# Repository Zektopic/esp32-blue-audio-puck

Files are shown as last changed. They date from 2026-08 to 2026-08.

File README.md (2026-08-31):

# BlueAudio Puck

**Turn wired headphones wireless.** A pocket-sized Bluetooth audio receiver: it
pairs with a phone or computer as an A2DP sink, decodes the stream on an ESP32,
runs it through a parametric equaliser, and pushes PCM out over I²S to an
external DAC and headphone amplifier feeding a 3.5 mm jack.






> [!IMPORTANT]
> **Original ESP32 only.** A2DP rides on Bluetooth Classic (BR/EDR), which
> Espressif removed from the ESP32-S3 and ESP32-C3. Those parts are BLE-only and
> cannot run this firmware — and they cannot fall back to LE Audio either, since
> that needs BLE 5.2 isochronous channels and they are 5.0.

---

## What it does

| | |
| --- | --- |
| **A2DP sink** | Pairs as a headphone. SBC decode, 16/32/44.1/48 kHz, mono or stereo. |
| **I²S output** | 16-bit PCM to an external DAC. APLL-clocked for accurate 44.1 kHz. |
| **AVRCP, both roles** | Phone's volume slider works; track metadata comes back; buttons drive transport. |
| **Parametric EQ** | Five biquad bands per channel, sample-rate aware, ~16% of one core when fully active. |
| **OLED status screen** | 128x64 SSD1306 over I2C: signal, track, artist, transport, volume, battery. |
| **Battery gauge** | ADC on a divider, Li-po curve, low and critical warnings. |
| **Physical UI** | One multi-function button, optional volume keys, optional PWM status LED. |
| **Power policy** | Capped TX power, 80–160 MHz frequency scaling, deep sleep on idle. |
| **Bounded pairing** | Discoverable only when you ask for it, not permanently. |

## Signal chain

```mermaid
flowchart LR
    SRC["Phone / PC<br/><i>A2DP source</i>"]
    subgraph PUCK["BlueAudio Puck"]
        direction LR
        BT["ESP32<br/>Bluedroid A2DP sink<br/>SBC decode"]
        DSP["Ring buffer<br/>+ EQ + volume"]
        DAC["PCM5102A<br/>I²S DAC"]
        AMP["Headphone amp"]
        OLED["SSD1306 OLED<br/><i>I²C</i>"]
        BATT["Li-po + divider<br/><i>ADC</i>"]
    end
    JACK["3.5 mm<br/>headphones"]

    SRC -- "Bluetooth Classic" --> BT
    BT -- "PCM frames" --> DSP
    DSP -- "I²S" --> DAC
    DAC -- "line level" --> AMP
    AMP --> JACK
    BT -. "track, volume" .-> OLED
    BATT -. "percent" .-> OLED
```

## Firmware architecture

The single rule everything else follows: **Bluedroid callbacks only enqueue.**
Anything slow in stack context stalls the radio and comes out as dropouts.

```mermaid
flowchart TD
    subgraph BTCTX["Bluetooth stack context — never blocks"]
        A2DP["A2DP data callback"]
        EVT["GAP / A2DP / AVRCP<br/>event callbacks"]
    end
    subgraph APPCTX["Application task — core 0"]
        WORK["work dispatcher<br/><i>bt_core</i>"]
    end
    subgraph AUDCTX["Audio writer task — core 1"]
        RB[("ring buffer<br/>32 kB")]
        EQ["biquad cascade<br/><i>audio_dsp</i>"]
        VOL["volume gain"]
        I2S["i2s_channel_write"]
    end

    A2DP -- "non-blocking send" --> RB
    EVT -- "dispatch" --> WORK
    WORK -- "start / stop / format" --> RB
    RB --> EQ --> VOL --> I2S

    classDef ctx fill:none,stroke-dasharray:4 3
    class BTCTX,APPCTX,AUDCTX ctx
```

Every cost — the blocking I²S write, the EQ, the gain — lives on the writer
task, pinned to the core the radio is not using.

### Components

| Component | Responsibility |
| --- | --- |
| [`bt_core`](components/bt_core/) | Stack bring-up, work queue between Bluedroid and the app task, bond management |
| [`audio_sink`](components/audio_sink/) | I²S channel, ring buffer, writer task, volume gain |
| [`audio_dsp`](components/audio_dsp/) | Parametric biquad equaliser and its benchmark |
| [`puck_avrcp`](components/puck_avrcp/) | AVRCP controller and target: volume, metadata, transport keys |
| [`puck_ui`](components/puck_ui/) | Button gestures and PWM status LED |
| [`puck_display`](components/puck_display/) | SSD1306 panel driver, framebuffer, screens |
| [`puck_battery`](components/puck_battery/) | ADC sensing and the Li-po discharge curve |
| [`puck_power`](components/puck_power/) | TX power, frequency scaling, idle deep sleep |

These are written from scratch against the IDF v5.5 API rather than reusing the
ESP-IDF example's shared components, which are pulled in by `${IDF_PATH}` path
and would make the repository unbuildable anywhere else. See
[docs/design-notes.md](docs/design-notes.md) for what that surfaced.

## Hardware

The pin map follows the layout that lets a PCM5102A board sit **directly under**
an ESP32 devkit on short solder bridges, rather than the pins that happen to be
convenient on a breadboard.

| ESP32 | Signal | Goes to |
| --- | --- | --- |
| GPIO 4 | I²S BCK | PCM5102A `BCK` |
| GPIO 15 | I²S LRCK | PCM5102A `LRCK` |
| GPIO 2 | I²S DATA | PCM5102A `DIN` |
| GPIO 21 | I²C SDA | SSD1306 `SDA` |
| GPIO 22 | I²C SCL | SSD1306 `SCL` |
| GPIO 32 | BT1 | to GND — next track / volume up |
| GPIO 33 | BT2 | to GND — play/pause / pairing (RTC pin, wakes from deep sleep) |
| GPIO 27 | BT3 | to GND — previous track / volume down |
| GPIO 35 | Battery sense | divider midpoint (optional, unfitted by default) |
| 3V3, GND | Power | both boards |

> [!NOTE]
> **No MCLK/SCK wire to the DAC.** Solder the `SCK` bridge on the front of the
> PCM5102A instead and it derives its own clock from BCK. Leave the ESP32 pin
> beneath it unconnected — a strip of tape stops it shorting to anything.

> [!IMPORTANT]
> **GPIO 2 is the devkit's on-board LED pin and a strapping pin.** It now
> carries I²S data, so the on-board LED flickers with audio — harmless, and the
> reason `PUCK_LED_GPIO` defaults to *not fitted*. It also means the board may
> refuse to enter download mode if the DAC holds that line high during reset;
> holding **BOOT** while flashing works around it.

PCM5102A jumpers — these cause most "no sound" reports:

| Pin | Set to | Why |
| --- | --- | --- |
| SCK bridge | **soldered** | Runs the internal PLL, so no MCLK wire is needed |
| XSMT | 3V3 | Release soft-mute. Low means muted. |
| FMT | GND | I²S (Philips) frame format, which is the firmware default |
| FLT | GND | Normal latency filter |
| DEMP | GND | De-emphasis off |

**Battery sensing** is optional and off by default. To fit it, run a divider
from the cell to GPIO 35 — two 100 kΩ resistors give 2:1, fits the ADC range
with a full 4.2 V cell, and draws about 21 µA — then set
`PUCK_BATTERY_ADC_GPIO=35` and the ratio to match your resistors.

Full parts discussion, power budget and the roadmap to a custom board:
[docs/hardware.md](docs/hardware.md).

## Building

Requires **ESP-IDF v5.5.4**.

```powershell
& 'C:\Espressif\tools\Microsoft.v5.5.4.PowerShell_profile.ps1'
idf.py set-target esp32
idf.py build
idf.py -p COM10 flash monitor
```

`sdkconfig` is generated and gitignored; `sdkconfig.defaults` is the source of
truth. Project settings live under **BlueAudio Puck** in `idf.py menuconfig`.

Expected first output:

```
I (593) puck: BlueAudio Puck booting (IDF v5.5.4)
I (603) audio_sink: ready: bck=4 ws=15 dout=2, 32 kB buffer, prefetch 25%
I (603) audio_dsp: 5-band equaliser ready at 44100 Hz (off, 0 active)
I (613) ssd1306: 128x64 panel at 0x3c on SDA=21 SCL=22
I (1313) bt_core: controller up, address ...
I (1373) puck: no bonded sources; discoverable as "BlueAudio Puck"
```

> [!TIP]
> If flashing fails with `Wrong boot mode detected (0x13)`, hold the **BOOT**
> button as the flash starts. Some devkits — and any board where GPIO 2 is
> loaded by the DAC — will not auto-reset into download mode.

## Using it

| Button | Tap | Hold |
| --- | --- | --- |
| **BT1** | Next track | Volume up — repeats while held |
| **BT2** | Play / pause | Pairing window (1.5 s) · forget all bonds (5 s) |
| **BT3** | Previous track | Volume down — repeats while held |

One action per press, no multi-tap timing to get right. Holding a volume button
sweeps rather than nudging once, at roughly four seconds end to end.

### The screen

| Screen | When |
| --- | --- |
| Splash | While the stack comes up |
| `PAIRING` | Discoverable, waiting for a source |
| `IDLE` | Connectable, nothing connected |
| Now playing | Signal, track and artist, transport state, volume bar, battery |

The top-left **signal meter** shows link quality while a source is connected.
It is hidden when nothing is connected, because bars against no link would be
meaningless. Note what Bluetooth Classic actually reports — see below.

The track title scrolls when it is too long, pausing at each end — continuous
sliding is much harder to read. Volume changes raise a brief toast over the
bottom of the screen. Battery shows as a percentage and an icon, or `USB` when
no sense divider is fitted.

> [!NOTE]
> **The signal meter will usually read full, and that is correct.** Bluetooth
> Classic does not report absolute signal strength. It reports a delta from the
> *Golden Receive Power Range* — the window the controller works to keep the
> link inside — so **zero means healthy**, not "no signal". The value only goes
> negative once the link is genuinely struggling. Read the bars as *fine /
> getting worse / about to drop out*, not as dBm.

At start-up the panel runs a **self test** — solid fill, checkerboard, then a
border — before any text is drawn. None of it uses the font, which is the
point: it separates a bus or panel fault from a text-rendering fault.

### The optional LED

| LED | Meaning |
| --- | --- |
| Fast blink | Discoverable, waiting for a source |
| Slow breathe | Connected, not streaming |
| Steady dim | Audio playing |
| Triple flash | Something failed to start |

Unfitted by default, because GPIO 2 now carries I²S data and the screen shows
the same states in words.

Volume normally comes from the phone over AVRCP absolute volume. Dedicated
volume buttons are optional and unfitted by default.

## Configuration

All under `idf.py menuconfig` → **BlueAudio Puck**. Every GPIO accepts `-1` for
"not fitted".

| Option | Default | Notes |
| --- | --- | --- |
| `PUCK_BT_DEVICE_NAME` | `BlueAudio Puck` | Shown in the pairing list |
| `PUCK_I2S_BCK/LRCK/DOUT_GPIO` | 4 / 15 / 2 | Direct-solder layout |
| `PUCK_I2C_SDA/SCL_GPIO` | 21 / 22 | `-1` disables the display |
| `PUCK_DISPLAY_I2C_ADDRESS` | 0x3C | Some modules strap to 0x3D |
| `PUCK_DISPLAY_CONTRAST` | 127 | |
| `PUCK_DISPLAY_SELF_TEST` | on | ~1.4 s of boot time |
| `PUCK_RSSI_POLL_SECONDS` | 3 | How often the signal meter updates |
| `PUCK_BATTERY_ADC_GPIO` | 35 | ADC1 pins only (32–39); `-1` if no divider |
| `PUCK_BATTERY_DIVIDER_RATIO_X100` | 200 | 2:1; must match your resistors |
| `PUCK_BT1/BT2/BT3_GPIO` | 32 / 33 / 27 | Active low, internal pull-up |
| `PUCK_VOLUME_STEP` | 6 | Per repeat, of 127 |
| `PUCK_LED_GPIO` | -1 | GPIO 2 is now I²S data |
| `PUCK_I2S_SLOT_FORMAT` | Philips | Must match the DAC's `FMT` pin |
| `PUCK_I2S_USE_APLL` | on | Accurate 44.1 kHz, slightly more current |
| `PUCK_AUDIO_RINGBUF_KB` | 32 | Larger rides out radio retries, costs RAM and latency |
| `PUCK_AUDIO_PREFETCH_PERCENT` | 25 | ≈46 ms cushion; also what an underrun costs to rebuild |
| `PUCK_AUDIO_WRITER_CORE` | 1 | Keep off core 0, which runs the radio |
| `PUCK_EQ_BANDS` | 5 | A ceiling, not a fixed price — flat bands cost nothing |
| `PUCK_EQ_ENABLED_AT_BOOT` | off | Starts transparent |
| `PUCK_EQ_BENCHMARK_AT_BOOT` | off | Times the cascade; see below |
| `PUCK_PAIRING_WINDOW_SECONDS` | 120 | How long a long press stays discoverable |
| `PUCK_BT_TX_POWER_LEVEL` | 7 (+9 dBm) | Ceiling; lower it for runtime |
| `PUCK_BT_TX_POWER_MIN_LEVEL` | 4 (0 dBm) | Floor power control may drop to |
| `PUCK_CPU_MAX/MIN_FREQ_MHZ` | 160 / 80 | Dynamic frequency scaling |
| `PUCK_IDLE_SLEEP_MINUTES` | 15 | Counts only while disconnected; 0 disables |

## Measured

| What | Result |
| --- | --- |
| EQ cost, 5 stereo biquad sections | 1337 µs per 360-frame block = **16% of one core** at 160 MHz |
| EQ cost per band | ~3.2% of a core, so roughly 30 sections before saturating one |
| OLED bus scan | One device ACKs at **0x3C** on SDA 21 / SCL 22 |
| Full-frame OLED refresh | 1025 bytes at 400 kHz ≈ 21 ms, hence a few Hz refresh |
| Firmware image | ~1.04 MB (needs the large single-app partition; the 1 MB default does not fit) |
| Free heap after boot | ~210 kB |
| Pairing window | Closes at 120.0 s, verified on hardware |

Power draw has **not** been measured. The estimates in
[docs/hardware.md](docs/hardware.md) are datasheet-derived, and devkit
measurements would be meaningless anyway — the USB-UART bridge and the AMS1117
regulator dominate a devkit's draw whatever the firmware does.

## Documentation

- [hardware/](hardware/) — KiCad schematic and PCB for a single-board version (unrouted, unfabricated)
- [docs/hardware.md](docs/hardware.md) — parts, wiring, power budget, board roadmap
- [docs/design-notes.md](docs/design-notes.md) — why the firmware is shaped this way, and the IDF bugs it avoids
- [docs/troubleshooting.md](docs/troubleshooting.md) — no sound, no pairing, dropouts, build failures
- [SECURITY.md](SECURITY.md) — threat model, pairing decisions, accepted risks

## Status

Working: builds, boots, pairs, advertises correctly, AVRCP negotiates, power and
UI subsystems initialise. Verified on an ESP32-WROOM devkit.

**Not yet verified:** audio actually coming out, and what the OLED renders. The
I²C bus and the panel address are confirmed by a scan on real hardware, but the
glyphs and layout have not been seen. The I²S configuration, the EQ response and
the end-to-end audio path are reasoned against the ESP-IDF v5.5.4 driver
sources, not heard. Battery sensing has no cell fitted, so only its
"not fitted" path runs.

## Prior art

Written from scratch, but these informed the design and are worth reading:

- [WillyBilly06/ESP32-A2DP-SINK-WITH-CODECS-UPDATED](https://github.com/WillyBilly06/ESP32-A2DP-SINK-WITH-CODECS-UPDATED) — LDAC/aptX/AAC patched into the IDF stack, which proves the SBC ceiling is firmware and not silicon
- [YetAnotherElectronicsChannel/ESP32_4CH_DSP_BT_AMPLIFIER](https://github.com/YetAnotherElectronicsChannel/ESP32_4CH_DSP_BT_AMPLIFIER) — parametric EQ with a Wi-Fi config UI, full schematics and gerbers
- [ESP32 as BT receiver with DSP capabilities](https://hackaday.io/project/166122-esp32-as-bt-receiver-with-dsp-capabilities) — biquads in the a2dp_sink render path; left the biquad budget as an open question, which [docs/design-notes.md](docs/design-notes.md) answers
- [gangg111/ESP32-Bluetooth-Audio-Receiver](https://github.com/gangg111/ESP32-Bluetooth-Audio-Receiver) — PCM5102A plus an OLED showing track metadata
- [pschatzmann/ESP32-A2DP](https://github.com/pschatzmann/ESP32-A2DP) — the reference Arduino-side A2DP library

## Licence

MIT — see [LICENSE](LICENSE).

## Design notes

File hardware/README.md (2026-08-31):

# BlueAudio Puck carrier board, rev A

KiCad 10 schematic and PCB for a single-board version of the puck: ESP32-WROOM-32U,
PCM5102A DAC, Li-po charging, two separate 3V3 rails, OLED header, three user
buttons and a 3.5 mm output — 60 × 64 mm, drawn to JLCPCB's two-layer rules.

| File | What it is |
| --- | --- |
| [`blueaudio-puck.kicad_pro`](blueaudio-puck.kicad_pro) | Project — open this |
| [`blueaudio-puck.kicad_sch`](blueaudio-puck.kicad_sch) | Schematic |
| [`blueaudio-puck.kicad_pcb`](blueaudio-puck.kicad_pcb) | Board |
| [`bom.csv`](bom.csv) | Bill of materials |
| [`preview/`](preview/) | SVG renders of both |
| [`scripts/`](scripts/) | The generator — see below |

## Read this before you order anything

> [!CAUTION]
> **Not finished: eight nets still need routing by hand.**
>
> Everything the generator lays is DRC-clean — **zero clearance violations,
> zero shorts, zero hole-clearance errors** under JLCPCB's rules. But 25 of 33
> nets are routed, not 33, and the remaining eight are unconnected copper:
>
> `+3V3A` · `AUDIO_L` · `CC1` · `CC2` · `DAC_LDOO` · `DAC_VNEG` · `I2S_BCK` · `I2S_LRCK`
>
> All eight are around the two fine-pitch parts — the TSSOP-20 DAC and the
> USB-C receptacle. Open the board in Pcbnew and its interactive router will
> finish them far faster and better than the one in `scripts/`. Do not order
> anything until DRC reports zero unconnected items.

> [!WARNING]
> **Nothing here has been fabricated or tested.** It passes ERC and the DRC
> checks that apply to an unrouted board. It has never been a physical object.
> Review the schematic against the datasheets before you spend money.

## Verification

Actually run, with the output quoted rather than summarised:

```
$ kicad-cli sch erc --severity-error --severity-warning
Found 4 violations                    # all lib_symbol_mismatch, see below

$ kicad-cli pcb drc --severity-error --severity-warning
Found 25 violations
Found 22 unconnected items
```

The schematic is clean: **zero electrical errors**, no unconnected pins, no
dangling labels, no malformed outline. All four ERC warnings are
`lib_symbol_mismatch` on KiCad's *derived* symbols — the two regulators and the
two transistors. Cosmetic; see below.

The board has **no electrical errors either**. Breaking the 25 down:

| Count | Kind | Status |
| --- | --- | --- |
| 22 | `unconnected_items` | **Must fix** — the eight unrouted nets |
| 15 | `silk_over_copper` | Cosmetic; every fab ignores it |
| 10 | `silk_overlap` | Cosmetic |

No `clearance`, no `shorting_items`, no `hole_clearance`. That took three fixes
to the router's geometry, each of which had produced copper that looked right
and was not — they are written up in the file that makes them:

- **A track is not a point.** A 0.4 mm power track centred on a 0.25 mm grid
  cell spills into its neighbours; checking only the cell it steps through let
  it sit 0.15 mm from a pad. Same for vias, which are 0.6 mm across — one
  landed on top of another net's track.
- **Clearance belongs in the check, not the map.** Growing a clearance halo
  around every pad *and* checking a track's own clearance against it demanded
  the gap twice, which makes escaping a 0.65 mm pitch TSSOP impossible.
- **Holes are stricter than copper.** Copper-to-hole is 0.25 mm where
  copper-to-copper is 0.15 mm, so drilled pads are claimed slightly larger than
  their copper.

The router still gets 25 of 33 nets rather than all of them. It routes in order
and never rips up an earlier net to make room, which is the difference between
it and a real autorouter.

The two ERC warnings are `lib_symbol_mismatch` on `AP2112K-3.3` and
`LP2985-3.3`. Both are KiCad *derived* symbols (`extends`), and the generator
flattens them to embed them; the flattened copy differs cosmetically from the
library's. Connectivity and pin numbering are unaffected. Eeschema's
*Update Symbols from Library* clears it.

The silkscreen warnings are reference designators sitting over pads. Normal for
auto-placed boards, ignored by every fab, and worth tidying only once placement
is final.

## How it is generated

Both files come from **one** netlist, in [`scripts/design.py`](scripts/design.py).

That matters more than it sounds. A schematic and a PCB authored separately
disagree about connectivity, and KiCad does not tell you until someone runs ERC
and gets a wall of errors. One source, two emitters, no drift.

```
scripts/design.py         parts, nets, no-connects, board size  <- edit this
scripts/kisym.py          pulls symbols out of the KiCad libraries
scripts/check_sheet.py    catches stubs from different nets touching
scripts/gen_schematic.py  emits the .kicad_sch
scripts/gen_pcb.py        emits the .kicad_pcb (needs KiCad's python)
```

To regenerate:

```bash
cd hardware/scripts
python design.py          # netlist self-check
python check_sheet.py     # no two nets touching
python gen_schematic.py
"C:/Users/manup/AppData/Local/Programs/KiCad/10.0/bin/python.exe" gen_pcb.py
```

`gen_pcb.py` needs KiCad's bundled interpreter — `pcbnew` lives only there.

Symbols and footprints are copied from the installed libraries rather than
transcribed, so the output files are self-contained and open on a machine with
no libraries configured. A hand-typed pin table is exactly the kind of error
nothing but a human eye can catch.

### Once you edit it by hand

The generators overwrite their outputs. Move the files out of `hardware/`, or
stop regenerating, once you start editing in KiCad — which you will, because
routing is the next step.

## The design

```
USB-C ──> MCP73831 ──> Li-po ──┬──> AP2112K ──> +3V3  ──> ESP32, OLED, DAC digital
                               └──> LP2985  ──> +3V3A ──> DAC analogue
```

**Two regulators from the cell, not one.** The DAC's analogue rail gets its own
low-noise LP2985 with a bypass capacitor. Sharing a rail with a Bluetooth radio
is what makes a DAC hiss, and `docs/hardware.md` said so before this board
existed.

**No MCLK.** The PCM5102A has `SCK` grounded and runs from its internal PLL,
matching the hand-built prototype and what the firmware expects.

**JP1 sits in series with I²S data on GPIO 2.** That pin is a boot strapping
pin, and a DAC loading it is why the prototype needs BOOT held to flash. Lift
the jumper and the board flashes normally.

**Battery sense** is R7/R8, a 2:1 divider into GPIO 35, matching
`PUCK_BATTERY_DIVIDER_RATIO_X100=200`.

**Three user buttons** on GPIO 32/33/27, matching the firmware — SW1 is BT1
(next / volume up), SW2 is BT2 (play-pause / pairing), SW3 is BT3 (previous /
volume down). All active low straight to ground; the ESP32's internal pull-ups
mean no external resistors. SW4 and SW5 are RESET and BOOT.

Note there is **no LED on GPIO 27** on this board. The Kconfig help for
`PUCK_LED_GPIO` suggests 27 for an external status LED, which would collide
with BT3 on a breadboard. Here the only LED is D1, the charge indicator on
`CHG_STAT`, so GPIO 27 is unambiguously BT3.

### Where it departs from `docs/hardware.md`

Both departures are deliberate and both are rev B work:

**No buck-boost.** `docs/hardware.md` specifies a TPS63020 for efficiency —
roughly 20–25% more runtime than an LDO. KiCad's standard library has no symbol
for it, and inventing one is precisely the silent error this generator exists to
avoid. Rev A uses LDOs and pays the efficiency.

**No headphone amplifier.** The PCM5102A is line level: audible on 32 Ω
headphones but quiet, exactly as the docs warn. A TPA6132A2 is the rev B
addition, and it is QFN-16 — it would make this board far harder to hand-build.

## Manufacturing rules

Written into the project file, so DRC enforces them rather than leaving them as
folklore. JLCPCB's standard two-layer process, with margin:

| | JLC minimum | Used here |
| --- | --- | --- |
| Track width | 0.127 mm | 0.20 mm |
| Clearance | 0.127 mm | 0.15 mm |
| Via drill | 0.20 mm | 0.30 mm |
| Via diameter | drill + 0.26 | 0.60 mm |
| Annular ring | 0.13 mm | 0.15 mm |
| Hole to hole | 0.50 mm | 0.50 mm |
| Track to outline | 0.20 mm | 0.50 mm |

Only clearance sits near a limit, and it is still 18% above JLC's floor. The
0.05 mm it frees up per side compared with KiCad's 0.2 mm default is most of
what lets the congested area route at all.

**Teardrops are configured but not generated.** The parameters are in the
project file; KiCad adds the actual teardrops on demand. Run *Edit → Teardrops
→ Add Teardrops* in Pcbnew once routing is finished — doing it before then
would only have to be redone.

## What is left to do

1. **Route the last eight nets** in Pcbnew: `+3V3A`, `AUDIO_L`, `CC1`, `CC2`,
   `DAC_LDOO`, `DAC_VNEG`, `I2S_BCK`, `I2S_LRCK`. All are around the TSSOP-20
   DAC and the USB-C part. The interactive router will do this in minutes.
2. **Add teardrops** once routing is done.
3. **Check the antenna keep-out.** The WROOM-32U has an external connector so
   there is no PCB antenna to clear, but leave the module's edge unpoured.
4. **Re-run DRC** and get it to zero before ordering anything.
5. **Review against datasheets.** Especially the MCP73831 programming resistor
   (R5 = 2 kΩ, about 500 mA) against your cell's charge rate.
6. **Rounded corners** were dropped — arcs whose endpoints did not meet left the
   outline open, and KiCad will not guess. Add them in Pcbnew, where the editor
   keeps the ends joined.

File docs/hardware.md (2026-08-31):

# Hardware

Parts, wiring, power budget and the route from a breadboard to a puck.

> [!NOTE]
> The pin map below is **as wired**. The I²C bus and OLED address are confirmed
> by a scan on the real board. Everything about audio and power is still
> unverified: no DAC has produced sound yet, no cell is fitted, and the power
> figures are datasheet-derived estimates rather than measurements.

## Why the original ESP32

A2DP rides on Bluetooth Classic (BR/EDR). Espressif removed Classic from every
chip after the original ESP32, so:

| Part | Bluetooth | A2DP sink? |
| --- | --- | --- |
| ESP32 (Xtensa) | Classic BR/EDR + BLE | **Yes** |
| ESP32-S3 | BLE 5.0 only | No |
| ESP32-C3 | BLE 5.0 only | No |

The S3 and C3 cannot fall back to LE Audio either — that needs BLE 5.2
isochronous channels and they are 5.0. This is silicon, not firmware.

Use a **WROOM-32U with an external antenna** if you can. A puck lives in a
pocket or bag with a body between it and the phone, and builders consistently
report better range with an external antenna than with the PCB one.

## The pin map, and why these pins

The layout lets a PCM5102A board sit **directly beneath** an ESP32 devkit,
joined by short solder bridges, instead of using whichever pins are convenient
on a breadboard. That is what makes it a puck rather than a project box.

| ESP32 | Signal | Goes to |
| --- | --- | --- |
| GPIO 4 | I²S BCK | PCM5102A `BCK` |
| GPIO 15 | I²S LRCK | PCM5102A `LRCK` |
| GPIO 2 | I²S DATA | PCM5102A `DIN` |
| GPIO 21 | I²C SDA | SSD1306 `SDA` |
| GPIO 22 | I²C SCL | SSD1306 `SCL` |
| GPIO 32 | BT1 button | to GND |
| GPIO 33 | BT2 button | to GND |
| GPIO 27 | BT3 button | to GND |
| GPIO 35 | Battery sense | divider midpoint (optional) |
| 3V3, GND | Power | both boards |

All three buttons wire straight between their pin and ground — the internal
pull-ups do the rest, so no external resistors. All three are RTC-capable pins,
though only BT2 is wired as the deep-sleep wake source: `ext0` watches exactly
one pin, and the ESP32's `ext1` can only wake on *all low* or *any high*,
neither of which means "any of three active-low buttons pressed".

Avoid GPIO 34–39 for buttons. They are input-only **and** have no internal
pull-up, so a switch on one of them floats until you fit your own resistor.

Three things about these pins are worth knowing before you solder.

**No MCLK wire.** Solder the `SCK` bridge on the front of the PCM5102A and it
derives its own clock from BCK. The ESP32 pin that would otherwise carry MCLK
is left unconnected — put tape over it so it cannot short to the DAC board
sitting on top.

**GPIO 2 is doing double duty.** It is the devkit's on-board LED pin, so that
LED now flickers with audio data. Harmless, and the reason `PUCK_LED_GPIO`
defaults to *not fitted*: an external status LED needs a free pin such as 27,
and with the OLED fitted it is largely redundant anyway.

**GPIO 2 and GPIO 15 are strapping pins.** Only during reset — driving them as
outputs afterwards is fine, which is what makes this layout work at all. The
practical consequence is that a DAC loading GPIO 2 can stop the board entering
download mode, so hold **BOOT** while flashing if `idf.py flash` reports
`Wrong boot mode detected (0x13)`.

### PCM5102A jumpers

These cause most of the "no sound" reports on these boards.

| Pin | Set to | Why |
| --- | --- | --- |
| SCK bridge | **soldered** | Runs the internal PLL, so no MCLK wire is needed |
| XSMT | 3V3 | Releases soft-mute. Low means muted. |
| FMT | GND | I²S (Philips) format — matches the firmware default |
| FLT | GND | Normal latency filter |
| DEMP | GND | De-emphasis off |

### The OLED

A 0.96" 128x64 SSD1306 on the I²C bus. Confirmed on this hardware:

```
I (606) i2cprobe:   ACK at 0x3c
I (616) i2cprobe: scan done, 1 device(s)
```

Modules ship strapped to **0x3C or 0x3D** depending on a solder jumper, so the
address is a Kconfig option. The driver probes before configuring anything and
says plainly when nothing answers, rather than producing a cascade of timeouts.

Most breakouts fit their own 4.7 kΩ pull-ups. The firmware also enables the
ESP32's internal pull-ups, which are weak (~45 kΩ) but adequate for a short
run at 400 kHz. A long or unreliable bus wants real resistors.

A full frame is 1025 bytes; at 400 kHz that is about 21 ms, which is why the
refresh task runs at a few hertz rather than at video rates.

The screen needs no extra hardware for the signal meter — link quality comes
from the Bluetooth controller, not from a sensor.

### Battery sensing

Optional and unfitted by default. A divider from the cell to an ADC1 pin:

- **Two 100 kΩ resistors** give 2:1 — a full 4.2 V cell reads 2.1 V at the pin,
  comfortably inside the ADC's ~3.1 V full scale at 11 dB attenuation, and the
  pair draws about 21 µA.
- **GPIO 35** is a good input: input-only, so it cannot be driven by mistake,
  and it is ADC1. ADC2 is shared with the Wi-Fi radio and is refused.
- Set `PUCK_BATTERY_DIVIDER_RATIO_X100` to match the resistors you actually
  fitted. A percentage from the wrong ratio is worse than no percentage.

A voltage-derived percentage is an estimate, not a fuel gauge — see
[design-notes.md](design-notes.md#battery-percentage-is-an-estimate).

If your breakout ties `FMT` high instead, switch the firmware to left-justified
under **BlueAudio Puck → audio output → I²S frame format**. A format mismatch
produces audio that is present but wrong, which is far harder to diagnose than
silence.

### Expectation setting

The PCM5102A is a **line-level output, not a headphone driver**. It will be
audible on 32 Ω headphones but quiet. That is fine for proving the chain; a real
headphone amplifier is the next phase, not this one.

## Phase 1 — proper analogue path

| Function | Part | Notes |
| --- | --- | --- |
| DAC + headphone amp | **CS43131** | One package, low power, drives 32 Ω comfortably. What commercial dongles use. |
| Alternative DAC | PCM5102A | Line level only |
| Alternative amp | TPA6132A2 | Pairs with the PCM5102A; more parts, easier to hand-solder |

## Phase 2 — power

| Function | Part | Notes |
| --- | --- | --- |
| Cell | 500–1000 mAh Li-po | Size decides runtime and therefore enclosure dimensions |
| Charger | BQ25180 | I²C status; MCP73831 if you want simple |
| Main rail | TPS63020 buck-boost | ~88–90% across the cell's range, and keeps working down to 3.0 V |
| DAC analogue rail | TPS7A20 LDO | Low noise, fed from the switcher's output |

**Do not run the DAC's analogue supply from the switcher directly.** Audio DACs
are unforgiving of noisy rails and you will hear it as hiss. Two-stage —
buck-boost to ~3.5 V for the ESP32, then a low-noise LDO down to 3.3 V for the
DAC's analogue pin only — costs almost nothing at a 25 mA load.

An LDO straight from the cell would be simpler, but its efficiency is
V_out ÷ V_in: 79% at a full 4.2 V cell, and it drops out around 3.4 V, stranding
the bottom of the cell's capacity. The buck-boost is worth roughly 20–25% more
runtime for one part.

## Power budget

> **Estimates only.** Datasheet figures and typical reported values. Nothing
> here has been measured on this build, and measuring on a devkit would not
> help — the CP210x bridge and the AMS1117 regulator dominate a devkit's draw
> whatever the firmware does.

At the 3.3 V rail while streaming:

| Component | Draw |
| --- | --- |
| ESP32 @ 160 MHz, BT Classic active | ~110 mA |
| PCM5102A | ~25 mA |
| Headphone amp (TPA6132A2 class) | ~10 mA |
| Status LED (averaged) | ~1 mA |
| **Total** | **~146 mA (≈482 mW)** |

The ESP32 is roughly three quarters of the budget. Every optimisation that is
not about the ESP32 is rearranging deck chairs.

By state:

| State | Draw | What is running |
| --- | --- | --- |
| Playing | ~146 mA | Everything |
| Connected, paused | ~65 mA | Link in a low-power mode, DAC muted |
| Deep sleep | ~10 µA | Custom board only |

Estimated runtime through an ~88% converter (≈148 mA from a 3.7 V nominal cell):

| Cell | Runtime |
| --- | --- |
| 500 mAh | ~3 h |
| 1000 mAh | ~6 h |
| 2000 mAh | ~12 h |

### Levers, ranked by what they actually buy

1. **A bigger cell.** Unglamorous, and by far the biggest lever. A 1000 mAh
   pouch is a couple of millimetres thicker and doubles runtime. Do this before
   any firmware cleverness.
2. **Buck-boost instead of an LDO.** ~20–25%.
3. **160 MHz instead of 240.** ~15%. Already the default here.
4. **Lower Bluetooth TX power.** Worth several mA, and the one lever here with
   a real cost: the default is now the +9 dBm maximum
   (`PUCK_BT_TX_POWER_LEVEL`). Capping it at 0 dBm saves current and throws
   away most of the link budget -- a puck in a pocket has a body between it and
   the phone, and 9 dB is nearly three times the free-space range. Reach for
   the cell size first.
5. **Deep sleep on disconnect.** Extends playback by nothing, but it is the
   difference between flat by morning and fine next week. Already implemented.
6. **Power-gate the headphone amp** using the 3.5 mm jack's switched contact and
   a load switch. Free hardware you already have in the connector.

### The honest comparison

A Qudelix 5K runs ~20 hours; a FiiO BTR7 ~9. They use purpose-built Bluetooth
audio SoCs that idle in single-digit milliamps with hardware codec engines. This
is a general-purpose MCU running a full software Bluetooth stack, and no amount
of tuning closes that gap.

That is the trade for firmware you control. Size the cell accordingly rather
than trying to optimise your way to parity.

## Codecs

Stock ESP-IDF is **SBC only**, which is the usual argument for eventually
replacing the ESP32 with a dedicated part like a Microchip BM83.

That argument is weaker than it looks. The
[ESP32-A2DP-SINK-WITH-CODECS-UPDATED](https://github.com/WillyBilly06/ESP32-A2DP-SINK-WITH-CODECS-UPDATED)
project patches LDAC, aptX, aptX-HD and AAC into the IDF Bluetooth stack. The
codec ceiling is a firmware limit, not a silicon one — worth establishing before
planning a board respin around a different SoC.

## Roadmap

```mermaid
flowchart LR
    P0["Phase 0<br/>devkit + PCM5102A<br/>USB power"] --> P1["Phase 1<br/>CS43131<br/>headphone amp"]
    P1 --> P2["Phase 2<br/>Li-po, buck-boost<br/>low-noise LDO"]
    P2 --> P3["Phase 3<br/>custom PCB<br/>printed enclosure"]
```

A KiCad schematic and board for phases 1 and 2 combined live in
[../hardware/](../hardware/): ESP32-WROOM-32U, PCM5102A, MCP73831 charging and
the two separate 3V3 rails this page argues for. It is **unrouted and
unfabricated**, and it departs from this page in two places -- LDOs instead of
the buck-boost, and no headphone amplifier -- both explained in
[../hardware/README.md](../hardware/README.md).

Nothing in the firmware is wasted if the brain changes later: the DAC, power,
enclosure and UI work all carry over, and only `bt_core` and `puck_avrcp` are
Bluetooth-specific.

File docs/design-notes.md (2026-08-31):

# Design notes

Why the firmware is shaped the way it is, and what went wrong on the way there.
This is the document to read before changing the audio path.

## The one rule

**Bluedroid callbacks only enqueue.**

`a2dp_data_cb` and every event callback run on Bluedroid's own task. Anything
slow there stalls the Bluetooth stack, which costs media packets, then link
supervision, then the connection. So:

- The A2DP data callback does one non-blocking `xRingbufferSend` and nothing else.
- Event callbacks do one non-blocking `bt_core_dispatch` and nothing else.
- Every cost — the blocking I²S write, the EQ, the volume gain — happens on the
  audio writer task, pinned to core 1, while the radio owns core 0.

Two consequences that look like over-engineering until you know the rule:

- `bt_core_dispatch` uses a **zero** queue timeout. Dropping work is the
  designed outcome; blocking would hand a misbehaving source a way to stall the
  stack 10 ms at a time.
- Logs on those paths are rate-limited. `ESP_LOGx` is a blocking UART write, and
  the paths that log most are the ones already under pressure.

## Why not reuse the IDF example's components

In ESP-IDF v5.5 the A2DP sink example was renamed `a2dp_sink` →
`a2dp_sink_stream` and its logic moved into shared components under
`examples/bluetooth/bluedroid/classic_bt/common/`, pulled in by `${IDF_PATH}`
paths in `main/idf_component.yml`.

Depending on those makes a repository unbuildable on any other machine or in CI.
So this firmware implements the same API surface itself — which had the side
effect of surfacing three defects that the example carries.

### Bug 1 — `i2s_channel_write(..., portMAX_DELAY)`

That parameter is **`timeout_ms`**, and the driver passes it to `pdMS_TO_TICKS`,
which is 32-bit. `portMAX_DELAY` overflows to roughly **twelve hours**.

It only bites around a stop. A disabled channel makes the write block on a
semaphore that only `i2s_channel_enable()` ever gives, so a writer that entered
the call just after `audio_sink_stop()` wedges — still holding a ring buffer
item. The window is roughly 0.2 ms of an 8.16 ms chunk period, and
`audio_sink_stop()` runs on every disconnect and every format change.

This firmware uses **100 ms**, about 18× the 5.44 ms descriptor period.

### Bug 2 — reconfiguring a live I²S channel

`i2s_channel_reconfig_std_clock` and `..._slot` assert
`state == I2S_CHAN_STATE_READY`, meaning the channel must be **disabled**. The
example calls them from its `AUDIO_CFG` handler while the channel is enabled and
ignores the return value, so the reconfiguration silently does nothing.

`audio_sink_set_format()` stops the stream, reconfigures, and restarts it.

### Bug 3 — deleting the writer task on disconnect

The example creates and `vTaskDelete`s its writer per connection, which can
delete a task in the middle of a write. Here the writer is created once at init
and parked on a task notification.

## The flush that silently did nothing

`audio_sink_stop()` drains the ring buffer so stale audio from the previous
stream does not play on resume — at the *new* sample rate, if the stop was for a
format change.

That drain was a no-op. FreeRTOS byte-mode ring buffers refuse a second
retrieval while one is outstanding (`prvCheckItemAvail` in `ringbuf.c`), so
draining while the writer held an item returned `NULL` immediately, freed
nothing, and reported no error.

The fix is the `parked` semaphore: the writer gives it before sleeping, and
`stop()` waits on it before touching the channel or the buffer.

## States with no wakeup source

The prefetch state machine had a subtle hole. The only `xTaskNotifyGive` that
started playback was on the successful *prefetch → playing* edge. Both
`audio_sink_start()` and the *dropping → playing* edge reached a runnable state
without notifying anyone.

The terminal sequence:

1. Buffer near full during normal playback.
2. Disconnect, or a 48 kHz reconfigure. The writer wedges (bug 1), and the
   flush no-ops.
3. `audio_sink_write` kept accepting — it never checked `running` — so the
   buffer hit 100% and entered drop mode.
4. On restart the writer parked. Drop mode's exit test asks whether the buffer
   has drained, which can never become true with a parked writer.
5. **Silence for the rest of the session.**

Fixed three independent ways: notify on both missing edges; refuse writes while
stopped, which removes the precondition entirely; and give the park a 100 ms
backstop so a missed edge is a hiccup rather than the end.

## Why the coefficients are double-buffered

A `biquad_coeffs_t` is five floats plus a flag. **No amount of `volatile` makes
a 24-byte struct update atomic.** The application task rewriting coefficients in
place while the writer reads them per sample can be observed half-published.

That is not a glitch that passes. A torn `(a1, a2)` pair can put the poles
outside the unit circle, and a recursive filter with unstable poles grows until
saturation turns it into a full-scale square wave — which **outlives** the
inconsistency, because nothing clears the state.

So: two coefficient sets, filled inactive-side and published by flipping an
index behind a release fence. The writer reads the index once per block. Filter
state is writer-owned and cleared through a `reset_pending` flag the writer
honours at block start, so the application task never touches it. Inner-loop
cost: zero.

The deterministic trigger was `puck_main.c`'s config handler, which restarts the
sink and only *then* recomputes coefficients — guaranteed on any 48 kHz source.

### Contrast: where `volatile` **is** enough

`running`, `mode`, `gain_q15`, `channels` and `processor` are all single-word
aligned accesses on an LX6 with no data cache on internal SRAM. Nothing can
tear. Every other defect in the audio path was *logical* — a missing wakeup
edge, a check-then-act window — not a memory-model problem.

## Coefficients are a function of the sample rate

Biquad coefficients depend on frequency ÷ sample rate. A source negotiating
48 kHz instead of 44.1 kHz shifts the entire EQ curve up by about 9%. So
`ESP_A2D_AUDIO_CFG_EVT` drives both `audio_sink_set_format()` and
`audio_dsp_set_sample_rate()`, and any rate change clears the filter state,
because state belonging to the old rate rings.

## How many biquads fit

The Hackaday DSP project this build draws on left that as an open question.
Measured on an ESP32-WROOM at 160 MHz with `PUCK_EQ_BENCHMARK_AT_BOOT`:

```
benchmark: 5 active section(s), 360 frames in 1337 us (8163 us of audio, 16% of one core)
```

**~3.2% of one core per stereo biquad section**, so roughly 30 sections before
one core is saturated — far more headroom than the usual assumption.

Two design choices follow from it:

- **Flat bands are excluded from the published set**, not flagged and skipped.
  A flat equaliser is the default; scanning bypass flags per sample to learn
  there is nothing to do is waste. With every band flat the pass returns on one
  comparison.
- **Live sections are copied to the stack once per block.** Read through the
  global they were reloaded through a pointer per sample per band.

Float was the right call. The ESP32 has a hardware FPU, the writer is pinned so
it effectively owns the coprocessor on its core, and the 96-byte context area is
reserved for every task regardless — so float costs the writer no extra stack.

## Latency and the prefetch cushion

Playback waits until the buffer is `PUCK_AUDIO_PREFETCH_PERCENT` full, then runs
until empty. That percentage is therefore also **what every underrun costs to
rebuild**.

At the 32 kB default, the original 60% was 111 ms. The DMA chain holds 33 ms and
keeps playing during a refill, so each underrun was an audible **78 ms gap** —
and 111 ms of added latency is enough to break lip-sync on video.

Now 25%, about 46 ms: still comfortably above the DMA depth and typical BR/EDR
retry windows.

## Frame alignment holds by arithmetic, not by construction

Interleaved 16-bit stereo frames are 4 bytes. Every A2DP PCM payload,
`RINGBUF_BYTES` (32768) and `WRITE_CHUNK_BYTES` (1440) are multiples of 4, so a
ring buffer wrap can never hand back a frame-straddling block. If any of the
three stopped being a multiple of 4, `audio_dsp_process` would silently swap
left and right for the rest of the stream — so there are `_Static_assert`s
documenting the invariant.

## Power: what firmware can and cannot reach

The ESP32 with Bluetooth Classic active is roughly three quarters of the current
budget. No firmware change closes the gap to a purpose-built Bluetooth audio SoC
— a Qudelix 5K manages ~20 hours because its SoC idles in single-digit
milliamps with hardware codec engines.

What firmware reaches: transmit power (the source is usually in the same
pocket), 80–160 MHz frequency scaling, and what the puck does with the hours it
spends in a bag.

**Light sleep stays off deliberately.** The controller keeps its reference clock
on the main crystal, which supports DFS but not light sleep, and light sleep
would break audio timing regardless.

**Sniff mode is not requested.** Bluedroid exposes `ESP_BT_PM_MD_SNIFF` only on
the mode-change *event* and offers no public call to request it — the controller
manages it internally. The firmware reports the link power mode rather than
claiming to control it.

**Deep sleep buys nothing during playback.** It is the difference between flat
by morning and fine next week.

## Three buttons beat one button with a timing test

The first scheme put everything on a single button: one tap for play/pause, two
for next, three for previous, and holds for pairing. It worked, and it was
unpleasant. Every track skip was a timing test, the multi-tap window added a
third of a second of latency to the most common action, and one bounced contact
turned play/pause into a track change.

Three buttons make each press unambiguous. Tap does one thing, hold does one
thing, and nothing depends on how fast the user's thumb is:

| Button | Tap | Hold | Extra |
| --- | --- | --- | --- |
| BT1 | next | volume up, repeating | — |
| BT2 | play/pause | pairing (1.5 s) | forget bonds (5 s) |
| BT3 | previous | volume down, repeating | — |

Two details are worth keeping if this is ever rewritten:

**Hold thresholds are per button, not global.** A volume button wants a short
threshold (500 ms) and a brisk repeat, because the user is watching a number
move and expects it to start moving. Pairing wants a long one (1.5 s) and no
repeat, because triggering it by accident is annoying and there is nothing on
screen to warn you. A single shared threshold has to be wrong for one of them.

**A hold suppresses the tap.** The tap fires on release and only if no hold
already fired, so holding for volume does not also skip a track when you let go.

The component reports `(button, event)` and knows nothing about tracks or
volume; the mapping lives in `puck_main.c`. That is the same separation the rest
of the firmware keeps -- `puck_ui` has never known what AVRCP is.

## The display runs at two rates

Track text and battery are read at **2 Hz**; the marquee animates at **8 Hz**
from that cached copy.

The split exists because `puck_avrcp_get_track()` takes the AVRCP mutex. A
display has no business taking that eight times a second, and the rest of this
codebase is careful to keep locks out of frequently-run paths. Caching costs a
struct copy and removes the question entirely.

A full frame is 1025 bytes over I²C at 400 kHz — about 21 ms. That sets the
ceiling on refresh rate regardless of what the CPU could manage.

Only the line that overflows scrolls, and it **pauses at both ends**. Text that
slides continuously is materially harder to read than text that stops.

## The signal meter measures something other than what it looks like

Bluetooth Classic has no absolute RSSI in the way Wi-Fi or BLE do.
`esp_bt_gap_read_rssi_delta()` returns a **delta from the Golden Receive Power
Range** — the window the controller is actively working to keep the link
inside. The header is explicit: *"The value zero indicates that the RSSI is
inside the Golden Receive Power Range."*

So zero means healthy, and a well-behaved link reports zero most of the time.
The meter therefore sits full during normal use, and only falls as the link
degrades. That is the correct behaviour, but it is the opposite of the
intuition a phone's signal bars build — hence the note in the README and the
Kconfig help, so nobody files it as a bug.

The thresholds mapping delta to bars are judgement, not specification:

| Delta | Bars |
| --- | --- |
| ≥ 0 | 4 |
| −1 … −5 | 3 |
| −6 … −15 | 2 |
| −16 … −30 | 1 |
| < −30 | 0 |

Two smaller decisions:

- **The meter is hidden when nothing is connected.** An empty meter reads as a
  fault; absent is honest about there being nothing to measure.
- **Empty bars still draw their baseline.** Without it, a genuinely weak signal
  and a broken renderer look identical on a monochrome panel.
- **A failed read invalidates the reading** rather than holding the last good
  value. A stale four bars on a dying link is worse than no bars.

## Why the panel driver is hand-written

Same reason the Bluetooth components are: this repository builds with nothing
but ESP-IDF, on any machine, with no network access at build time. Pulling
`espressif/esp_lcd_ssd1306` from the component registry would give a panel
driver but no text rendering, so a font would still be needed — and the whole
SSD1306 driver is about two hundred lines.

Two details in it are easy to get wrong:

- **The charge pump (`0x8D 0x14`) must be enabled.** Without it the panel is
  powered and configured but stays dark, which reads exactly like a dead
  display or a wiring fault.
- **Horizontal addressing mode** makes the framebuffer stream out in a single
  write, and it means one byte spans eight rows of one column — the same
  orientation the 5x7 font uses, so a glyph column drops in with no bit
  shuffling.

## The font is the one thing a compiler cannot check

`font5x7.c` is in its own file deliberately. A wrong glyph cannot be caught by
the compiler, by CI, or by any test without eyes on the panel — so when one
turns out to be wrong, the fix should be a one-line edit in a table rather than
surgery inside driver logic.

For the same reason the panel runs a **self test** before any text is drawn:
solid fill, checkerboard, then a border. None of it touches the font. A blank
screen after the self test passes means the rendering is wrong; a blank screen
during it means the bus or the panel is. Those have completely different fixes,
and without the self test the symptom is identical.

Anything outside printable ASCII renders as `?` rather than indexing past the
table — track metadata comes from a phone and is not to be trusted.

## Battery percentage is an estimate

Not a fuel gauge, and the code says so in as many words.

- Li-po terminal voltage **sags under load**. At the ~150 mA this device draws
  while streaming, the same cell reads materially lower than it does idle.
- The curve between 3.7 V and 3.9 V is **nearly flat**, and that span is most
  of the useful capacity.

So the curve is an eleven-point table rather than a formula — the real
discharge curve is flat in the middle and steep at both ends, and any linear
fit spends most of its life wrong. Readings are oversampled 16x and
exponentially smoothed, because otherwise the on-screen percentage flickers
with playback load.

ADC1 only. ADC2 is shared with the Wi-Fi radio and its readings become
unavailable whenever Wi-Fi is active; pinning to ADC1 removes the trap before
anyone adds the config portal that keeps getting discussed. And
`adc_cali_create_scheme_line_fitting` is allowed to fail rather than being
`ESP_ERROR_CHECK`ed — it needs eFuse calibration data that not every ESP32
carries.

## Things that bit during development

- **`esp_a2d_sink_disconnect(NULL)` panics.** It takes the address by value as
  an array parameter, so `NULL` is read straight through — `LoadProhibited`. It
  was harmless while pairing mode was only reachable from a button press with
  something connected; making boot enter pairing mode turned it into a boot
  loop. Always guard on an actual linked peer.
- **AVRCP metadata needs a deep copy *and* a matching free.** `attr_text` points
  into a buffer Bluedroid owns and reuses, and it is not NUL-terminated. A copy
  hook without a destructor leaks on every disposal path that skips the handler
  — which is exactly the path a burst of metadata drives.
- **SSP has no Kconfig symbol in v5.5.4.** The `CONFIG_EXAMPLE_SSP_ENABLED` in
  the IDF examples is example-local. SSP is `esp_bluedroid_config_t.ssp_en`.
- **Initialise AVRCP before `esp_a2d_sink_init()`**, or Bluedroid logs
  `A2DP Enable without AVRC` and builds an incomplete SDP record. Initialise it
  before the UI task too, or a button press can reach a mutex that does not
  exist yet.
- **Python on Windows writes CRLF by default.** Editing sources with it turns
  three-line changes into whole-file diffs. `.gitattributes` now pins LF.
- **Adding an I²C display collided with the audio path.** GPIO 22 was the I²S
  data pin and is the conventional I²C clock. Worth checking a new peripheral
  against every pin already claimed, not just the obvious one.
- **Some devkits will not auto-reset into download mode**, and a DAC loading
  GPIO 2 makes it worse. `Wrong boot mode detected (0x13)` means hold **BOOT**
  while flashing; it is not a firmware fault.

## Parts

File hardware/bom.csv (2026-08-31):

Reference | Value | Footprint | QUANTITY
C1,C4,C5,C7,C10,C18 | 100n | Capacitor_SMD:C_0805_2012Metric | 6
C2,C6,C14,C16 | 10u | Capacitor_SMD:C_0805_2012Metric | 4
C3,C8,C9,C11,C13,C15 | 1u | Capacitor_SMD:C_0805_2012Metric | 6
C12 | 4u7 | Capacitor_SMD:C_0805_2012Metric | 1
C17 | 10n | Capacitor_SMD:C_0805_2012Metric | 1
D1 | CHG | LED_SMD:LED_0805_2012Metric | 1
J1 | USB-C | Connector_USB:USB_C_Receptacle_HRO_TYPE-C-31-M-12 | 1
J2 | 3.5mm | Connector_Audio:Jack_3.5mm_CUI_SJ1-3513N_Horizontal | 1
J3 | OLED | Connector_PinHeader_2.54mm:PinHeader_1x04_P2.54mm_Vertical | 1
J4 | BATT | Connector_JST:JST_PH_S2B-PH-K_1x02_P2.00mm_Horizontal | 1
J5 | PROG | Connector_PinHeader_2.54mm:PinHeader_1x06_P2.54mm_Vertical | 1
JP1 | 0R | Resistor_SMD:R_0805_2012Metric | 1
Q1,Q2 | MMBT3904 | Package_TO_SOT_SMD:SOT-23 | 2
R1,R2,R9 | 10k | Resistor_SMD:R_0805_2012Metric | 3
R3,R4 | 5k1 | Resistor_SMD:R_0805_2012Metric | 2
R5 | 2k | Resistor_SMD:R_0805_2012Metric | 1
R6 | 1k | Resistor_SMD:R_0805_2012Metric | 1
R7,R8 | 100k | Resistor_SMD:R_0805_2012Metric | 2
SW1 | BT1 | Button_Switch_SMD:Panasonic_EVQPUJ_EVQPUA | 1
SW2 | BT2 | Button_Switch_SMD:Panasonic_EVQPUJ_EVQPUA | 1
SW3 | BT3 | Button_Switch_SMD:Panasonic_EVQPUJ_EVQPUA | 1
SW4 | RESET | Button_Switch_SMD:Panasonic_EVQPUJ_EVQPUA | 1
SW5 | BOOT | Button_Switch_SMD:Panasonic_EVQPUJ_EVQPUA | 1
U1 | ESP32-WROOM-32U | RF_Module:ESP32-WROOM-32U | 1
U2 | PCM5102A | Package_SO:TSSOP-20_4.4x6.5mm_P0.65mm | 1
U3 | MCP73831-2-OT | Package_TO_SOT_SMD:SOT-23-5 | 1
U4 | AP2112K-3.3 | Package_TO_SOT_SMD:SOT-23-5 | 1
U5 | LP2985-3.3 | Package_TO_SOT_SMD:SOT-23-5 | 1

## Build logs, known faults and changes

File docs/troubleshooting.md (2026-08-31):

# Troubleshooting

Ordered roughly by how often each one catches people.

## No sound at all

Work down the chain rather than guessing.

**1. Is the firmware even running?** Watch the serial log. You should see
`audio_sink: ready: bck=4 ws=15 dout=2` at boot and `stream started` when the
phone plays. If `stream started` never appears, the problem is the Bluetooth
link, not the audio path — jump to the pairing section.

**2. Check the PCM5102A jumpers.** These are responsible for most silent
breakouts:

- **SCK floating** → silence. It must be tied to **GND** to select the internal
  PLL. This is the single most common cause.
- **XSMT low or floating** → soft-mute engaged. It must be tied to **3V3**.
- FLT, DEMP → GND for normal operation.

**3. Check the frame format.** `FMT` tied to GND is I²S (Philips), which is the
firmware default. If your breakout ties it high, switch to left-justified under
**BlueAudio Puck → audio output → I²S frame format**. A mismatch usually gives
distorted or channel-swapped audio rather than silence.

**4. Remember the output is line level.** The PCM5102A is not a headphone
driver. On 32 Ω headphones it is audible but quiet. Quiet is not broken.

**5. Confirm the GPIOs.** The defaults are BCK 4, LRCK 15, DIN 2. If you wired
differently, change them in `menuconfig` — the boot log prints what the firmware
is actually using:

```
I (603) audio_sink: ready: bck=4 ws=15 dout=2, 32 kB buffer, prefetch 25%
```

**6. Check the SCK bridge.** The direct-solder layout runs no MCLK wire, so the
`SCK` bridge on the front of the PCM5102A must be soldered. Without it the DAC
has no clock source at all.

## Distorted, crackly or channel-swapped audio

- **Swapped channels or a persistent buzz** usually means a frame-format
  mismatch. See point 3 above.
- **Regular clicks** suggest ring buffer underruns. Look for
  `underrun, re-prefetching` at debug level, and raise
  `PUCK_AUDIO_PREFETCH_PERCENT` or `PUCK_AUDIO_RINGBUF_KB`.
- **`ring buffer full, shedding audio`** means the source is pushing faster than
  the writer drains. Check that the writer task is on core 1
  (`PUCK_AUDIO_WRITER_CORE`) and not competing with the radio on core 0.
- **Slow pitch drift over a long track** points at clock accuracy. Confirm
  `PUCK_I2S_USE_APLL` is on — the default divider does not hit 44.1 kHz exactly.

## The puck does not appear in the pairing list

**This is usually correct behaviour.** Once the puck remembers a source it is
*connectable but not discoverable*, so known devices can return while strangers
cannot see it. The boot log tells you which state it is in:

```
I (1663) puck: 1 bonded source(s); hold the button to pair another
```

**Hold BT2 for 1.5 seconds** to open a 120-second pairing window. The LED blinks
fast while it is open, and the screen shows `PAIRING`.

To start completely fresh, **hold BT2 for 5 seconds** — that forgets every
bonded source and reopens pairing.

If it is genuinely never discoverable:

- Check `A2DP Enable with AVRC` appears at boot. `without AVRC` means AVRCP
  failed to initialise before the A2DP sink.
- Confirm the chip is an original ESP32. The banner logs
  `This chip has no Bluetooth Classic` on an S3 or C3, which cannot run this
  firmware at all.

## It pairs, then immediately disconnects

- Some phones drop an A2DP sink that never sends AVRCP responses. Check for
  `avrcp: AVRCP up` at boot.
- If the log shows repeated `A2DP event N dropped; link state may be stale`, the
  work queue is overflowing. That is a symptom worth reporting rather than
  tuning around.

## It goes to sleep on its own

Expected. `PUCK_IDLE_SLEEP_MINUTES` defaults to 15 minutes and counts only while
**nothing is connected** — a connected but paused source never triggers it.
Press the button to wake, or set the option to 0 to disable.

If it sleeps and wakes immediately, the wake pin is floating. `ext0` wakes on a
level and the button pulls its pin low, so the RTC pull-up must be enabled — the
firmware does this, but only for RTC-capable pins. GPIO 34–39 are input-only and
GPIO 33 is the tested default.

Note only **BT2** wakes the puck. `ext0` watches a single pin, so BT1 and BT3
do nothing while it is asleep — that is by design, not a fault.

## Build failures

**`fatal error: freertos/ringbuf.h: No such file or directory`** and similar —
a component is missing from `PRIV_REQUIRES` in its `CMakeLists.txt`. The IDF
error message names the component that provides the header.

**`'ret' undeclared`** inside an `ESP_GOTO_ON_*` macro — those macros report
through a local named `ret`. Declare `esp_err_t ret = ESP_OK;` in the function.

**`region 'iram0_0_seg' overflowed`** or an app that does not fit — confirm
`CONFIG_PARTITION_TABLE_SINGLE_APP_LARGE=y`. The image is around 1.0 MB and the
default 1 MB factory partition does not fit it.

**`unknown kconfig symbol`** — the symbol does not exist in this IDF version.
`CONFIG_BT_SSP_ENABLED` is the trap here: it looks real because the IDF examples
define an *example-local* `CONFIG_EXAMPLE_SSP_ENABLED`, but SSP is a runtime
field (`esp_bluedroid_config_t.ssp_en`), not a build option.

**Whole-file diffs after editing** — Windows tooling wrote CRLF.
`.gitattributes` pins LF; run `git add --renormalize .` if it has already
happened.

## The screen is blank

The boot log answers this before you touch the wiring.

**Nothing at all in the log about the panel** — `PUCK_I2C_SDA_GPIO` or
`PUCK_I2C_SCL_GPIO` is `-1`, so the display is compiled out of the boot path.

**`no device at 0x3c on SDA=21 SCL=22`** — the driver probed and nothing
answered. Either the wiring is wrong, or the module is strapped to the other
address. SSD1306 boards ship at **0x3C or 0x3D** depending on a solder jumper;
try `PUCK_DISPLAY_I2C_ADDRESS=0x3D`. Check power and ground before the data
lines — a panel with no 3V3 obviously cannot ACK.

**`128x64 panel at 0x3c` but the screen stays dark** — the bus is fine and the
panel is answering. That points at the panel itself or its charge pump rather
than at wiring.

**The self test shows but text does not** — the bus, the panel and the driver
are all working, and the fault is in rendering. That is exactly why the self
test exists.

**Text appears but some glyphs are wrong** — that is the font table in
`components/puck_display/font5x7.c`, one five-byte row per character. It is in
its own file so a fix is a one-line edit.

**The screen is mirrored or upside down** — the segment remap (`0xA1`) and COM
scan direction (`0xC8`) in `ssd1306_init` set the orientation. Some modules are
built the other way round; swap them for `0xA0` and `0xC0`.

## A button does nothing, or does the wrong thing

The boot log lists every button it configured:

```
I (611) puck_ui: BT1 button on GPIO 32
I (611) puck_ui: BT2 button on GPIO 33
I (621) puck_ui: BT3 button on GPIO 27
```

**"BT3 button not fitted"** — that pin is set to `-1` in `menuconfig`.

**Nothing at all happens** — the firmware logs every press at info level
(`BT1 tap`, `BT2 hold`). If pressing produces no line, the switch is not
reaching the pin, or it is wired to 3V3 instead of GND. These are active low
with internal pull-ups: the switch belongs between the pin and **ground**.

**A tap registers as a hold** — the contact is staying closed, or the pin is
shorted low. Check the log timestamps: a tap and its release should be tens of
milliseconds apart.

**A hold never repeats** — only BT1 and BT3 repeat. BT2 fires once at 1.5 s and
again at 5 s, deliberately: nobody wants pairing mode to retrigger while their
thumb rests on the button.

## The signal bars are always full

**That is almost certainly correct.** Bluetooth Classic reports RSSI as a delta
from the Golden Receive Power Range, not as absolute strength, and zero — a
healthy link — maps to four bars. The value only goes negative once the link is
actually struggling, so on a desk next to the phone the meter should be full.

To see it move, walk away from the source until audio starts breaking up.

**The bars never appear at all** — they are drawn only while a source is
connected. On the pairing and idle screens there is nothing to measure.

**The bars show only their baselines** — a reading has not come back yet, or
the last read failed. The firmware invalidates the meter rather than showing a
stale value, so this is what a link in trouble looks like. `PUCK_RSSI_POLL_SECONDS`
sets how often it asks.

## The battery reading looks wrong

**It says `USB` but a cell is connected** — `PUCK_BATTERY_ADC_GPIO` is `-1`, so
the firmware never looks at the pin. The boot log says so plainly:

```
I (...) puck_batt: no battery sense fitted; assuming USB power
```

Set it to the divider pin (35 on the reference board). A working divider reads
about half the cell voltage: measure the midpoint with a meter and expect
~1.9 V for a cell around 3.8 V.

**It says `USB` and nothing is connected** — correct. That is the "not fitted"
report, not a failure.

**`implausible cell voltage ... check the divider resistors`** — the reading is
outside 2.5–4.6 V, so it is not a battery. Either the divider ratio does not
match the resistors actually fitted, or the ADC pin has nothing on it and is
reading noise.

**The percentage is nonsense** — check `PUCK_BATTERY_DIVIDER_RATIO_X100` against
the resistors you actually fitted. Two equal resistors are `200`. A wrong ratio
scales every reading.

**`no ADC calibration on this chip`** — that ESP32 has no eFuse calibration
data. Readings fall back to a nominal scaling and are approximate; nothing is
broken.

**It moves around during playback** — expected, and partly real. Li-po voltage
sags under load, and this device draws around 150 mA while streaming. The
reading is smoothed but the underlying sag is genuine. A voltage-derived
percentage is an estimate, not a fuel gauge.

## Flashing and monitoring

**`Wrong boot mode detected (0x13)! The chip needs to be in download mode.`** —
the board did not auto-reset into the bootloader. **Hold the BOOT button** as
the flash starts and release it once it begins writing. Some devkits never
auto-reset reliably, and a DAC loading GPIO 2 makes it worse, since that line is
both I²S data and a strapping pin.

**`Could not open COMn, the port is busy`** — something else holds it. A VS Code
serial monitor, a previous `idf.py monitor`, or a script that did not close its
handle. Close them and retry.

**The port number changed** — a different USB-serial chip enumerates as a
different port. Check which is present rather than assuming:

```powershell
[System.IO.Ports.SerialPort]::getportnames()
```

**`idf.py monitor` hangs a non-interactive shell.** It is interactive by design.
To capture a log from a script, open the port directly and pulse RTS to reset:

```powershell
$p = New-Object System.IO.Ports.SerialPort COM10,115200,None,8,one
$p.Open(); $p.DtrEnable = $false; $p.RtsEnable = $true
Start-Sleep -Milliseconds 200; $p.DiscardInBuffer(); $p.RtsEnable = $false
Start-Sleep -Seconds 5
$p.ReadExisting(); $p.Close()
```

Replace `COM10` with whatever the port scan above reports.

## Boot loops

Read the panic line. `Guru Meditation Error: Core 0 panic'ed (LoadProhibited)`
is a null or bad pointer dereference.

One found in this project, worth knowing: **`esp_a2d_sink_disconnect(NULL)`
panics.** It takes the address by value as an array parameter, so `NULL` is read
straight through. Always guard on an actually-connected peer.

To recover a bricked-looking board, hold GPIO 0 low during reset to enter the
serial bootloader, then flash normally.

## Measuring what is actually happening

**What is on the I²C bus.** The display driver probes its configured address at
start-up and logs the result either way, so the boot log already tells you
whether the panel answered.

**EQ cost.** Enable `PUCK_EQ_BENCHMARK_AT_BOOT` and read the log — it reports
microseconds per block and the share of one core, with every band forced active.
No DAC or audio source needed. Turn it back off afterwards.

**Buffer health.** `audio_sink_get_stats()` returns packets accepted, payloads
dropped, underruns and current buffer occupancy. The counters are the reliable
signal; the logs on those paths are deliberately rate-limited.

**Power.** Do not bother measuring on a devkit — the CP210x bridge and the
AMS1117 regulator dominate its draw whatever the firmware does. Meaningful
numbers need a bare module on your own board.

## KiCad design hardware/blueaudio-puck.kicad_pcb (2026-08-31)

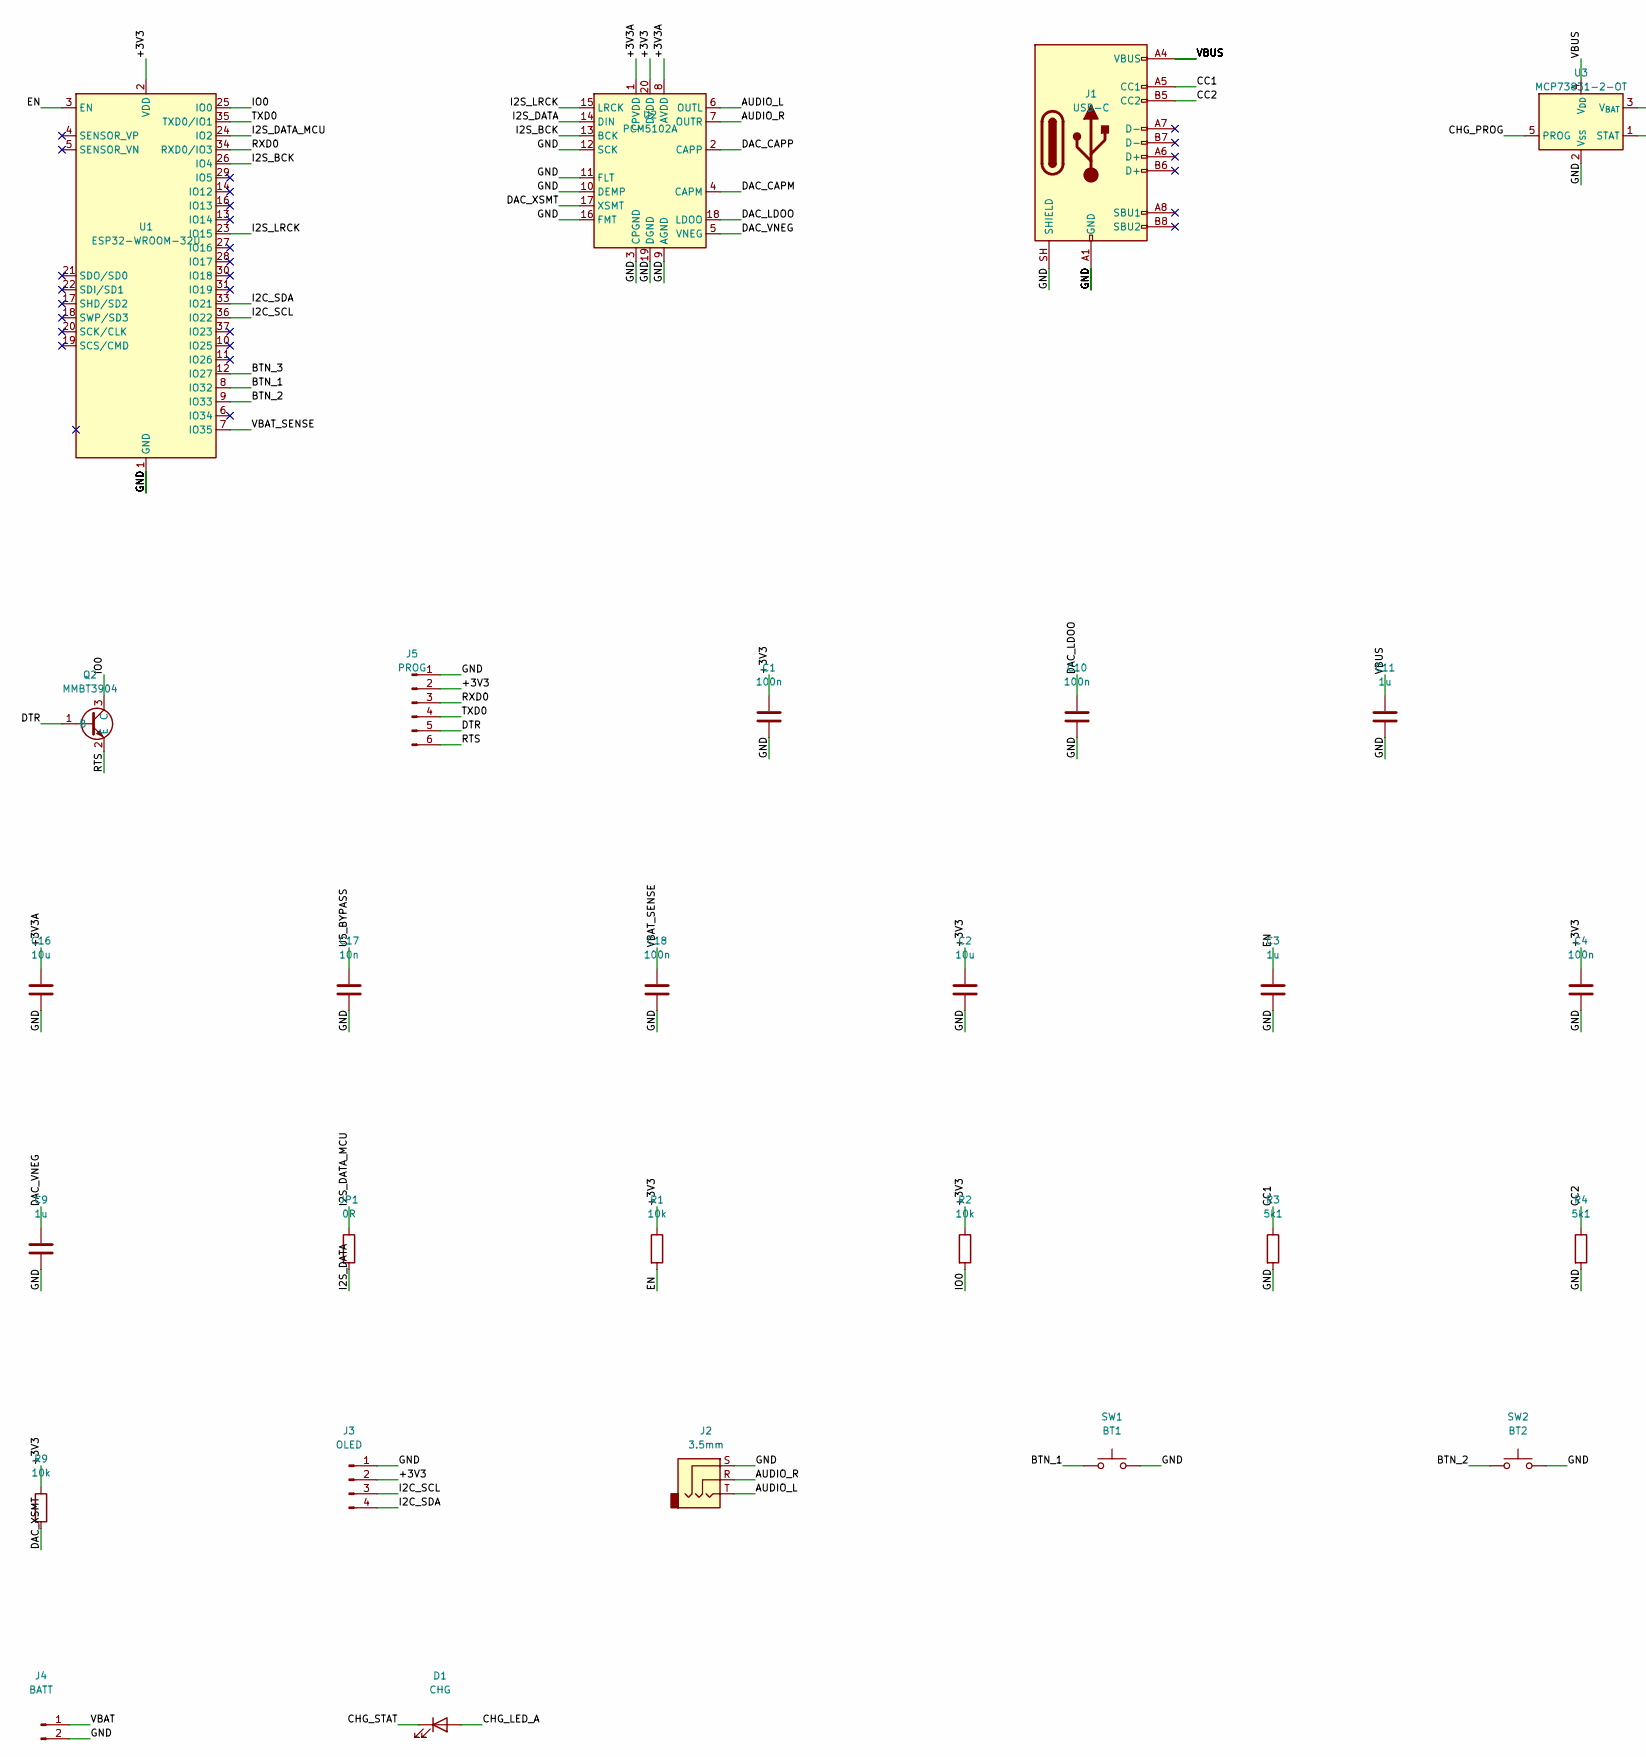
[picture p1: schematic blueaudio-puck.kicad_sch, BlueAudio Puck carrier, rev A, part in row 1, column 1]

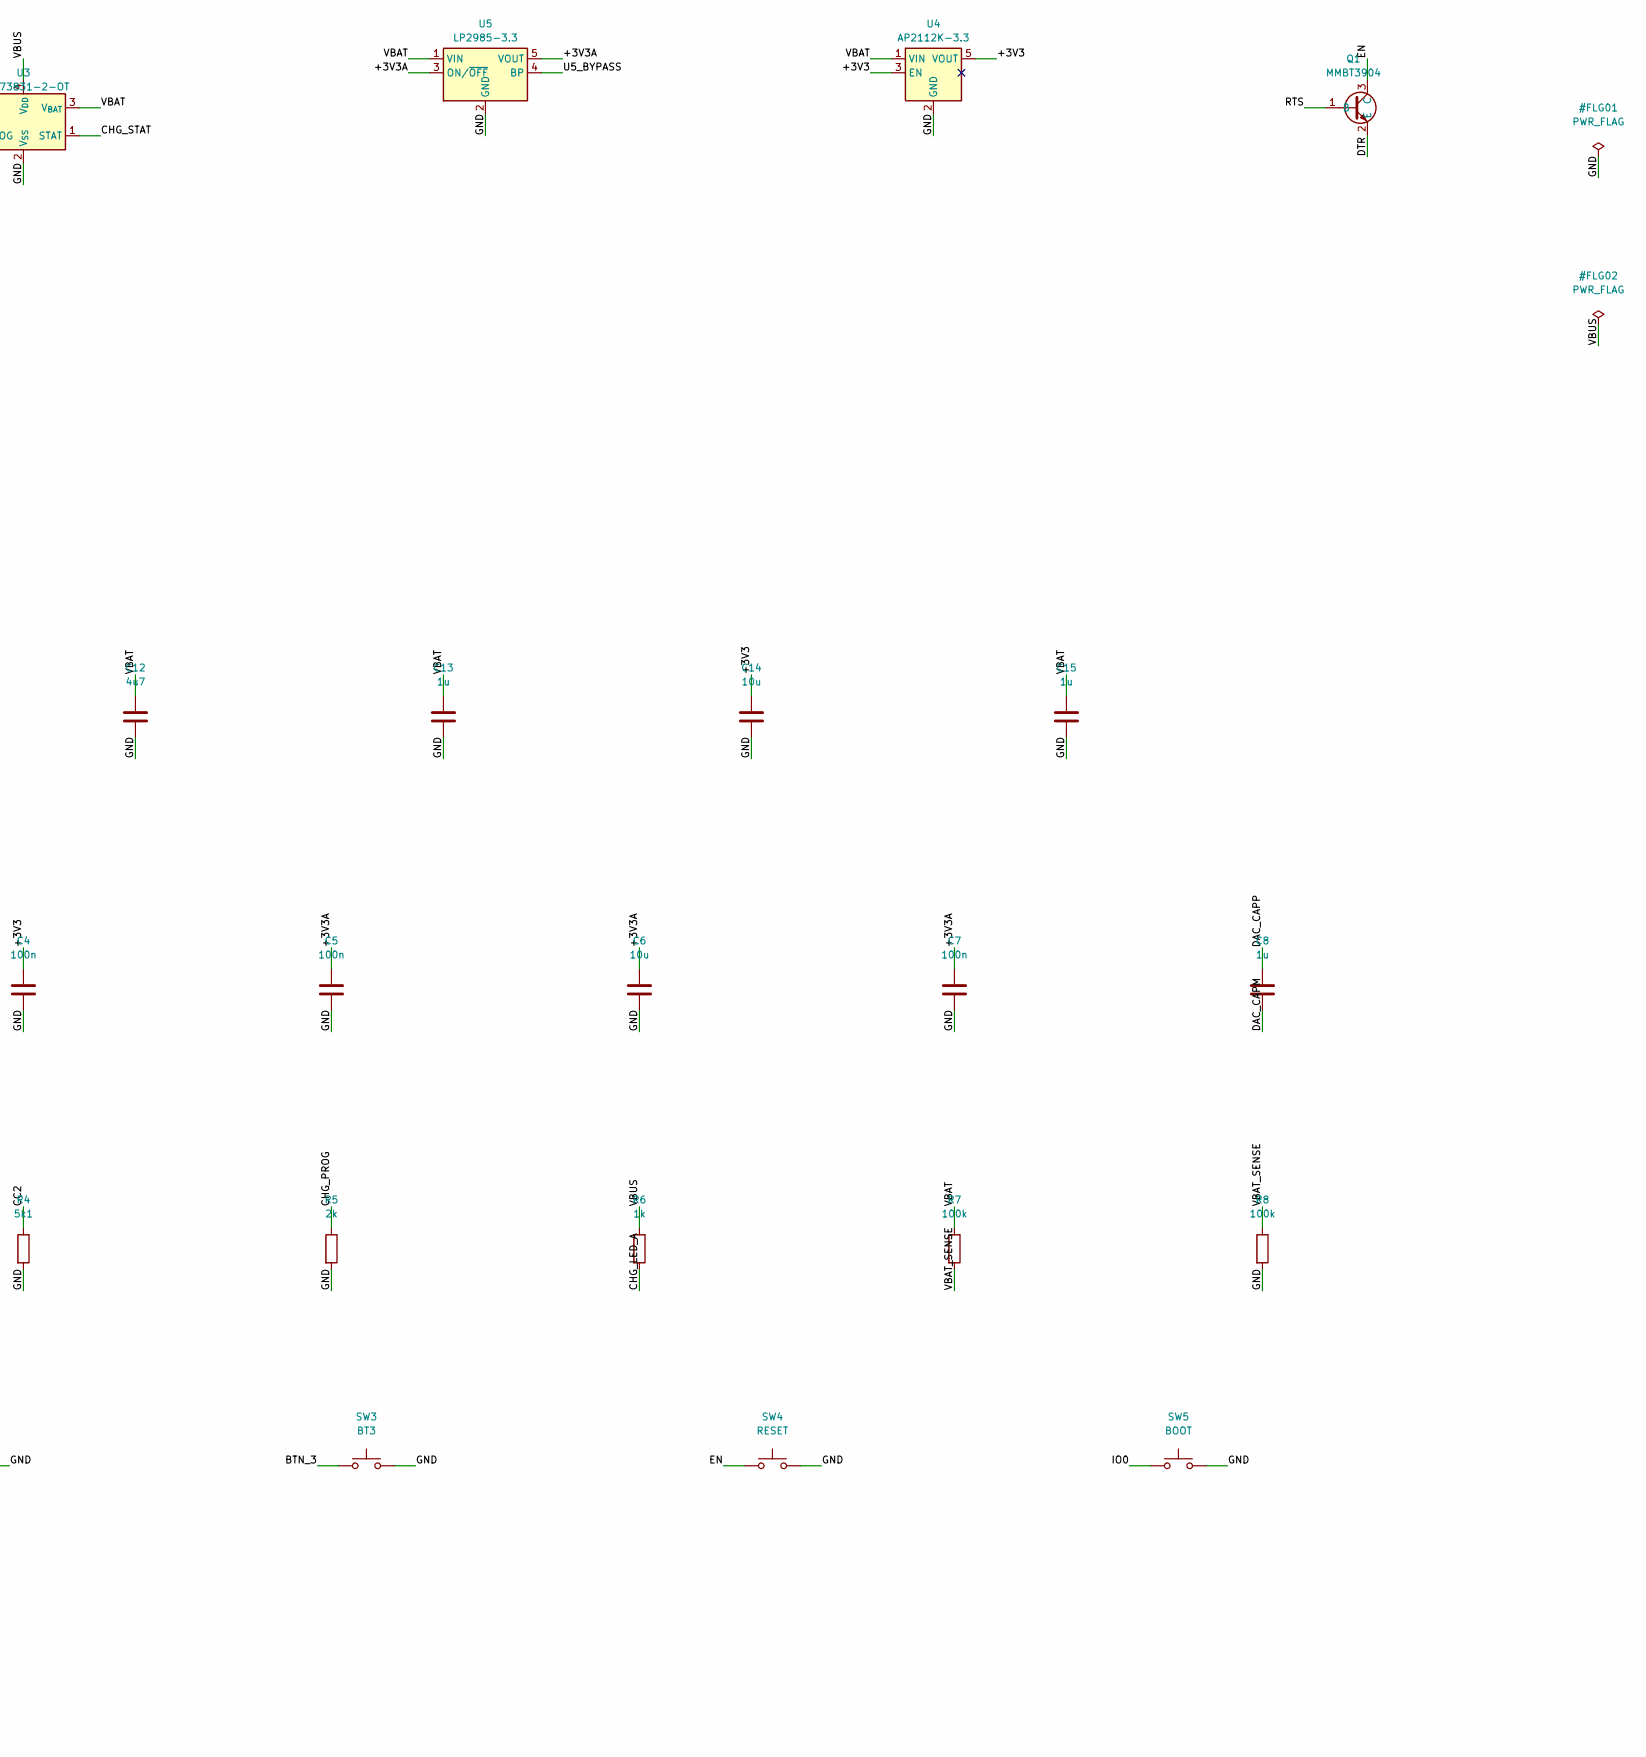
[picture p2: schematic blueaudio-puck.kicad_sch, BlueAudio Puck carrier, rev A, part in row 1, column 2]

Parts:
C1, C4, C5, C7, C10, C18: 100n; C_0805_2012Metric
C2, C6, C14, C16: 10u; C_0805_2012Metric
C3, C8, C9, C11, C13, C15: 1u; C_0805_2012Metric
C12: 4u7; C_0805_2012Metric
C17: 10n; C_0805_2012Metric
D1: CHG; LED_0805_2012Metric
J1: USB-C; USB_C_Receptacle_HRO_TYPE-C-31-M-12
J2: 3.5mm; Jack_3.5mm_CUI_SJ1-3513N_Horizontal
J3: OLED; PinHeader_1x04_P2.54mm_Vertical
J4: BATT; JST_PH_S2B-PH-K_1x02_P2.00mm_Horizontal
J5: PROG; PinHeader_1x06_P2.54mm_Vertical
JP1: 0R; R_0805_2012Metric
Q1, Q2: MMBT3904; SOT-23
R1, R2, R9: 10k; R_0805_2012Metric
R3, R4: 5k1; R_0805_2012Metric
R5: 2k; R_0805_2012Metric
R6: 1k; R_0805_2012Metric
R7, R8: 100k; R_0805_2012Metric
SW1: BT1; Panasonic_EVQPUJ_EVQPUA
SW2: BT2; Panasonic_EVQPUJ_EVQPUA
SW3: BT3; Panasonic_EVQPUJ_EVQPUA
SW4: RESET; Panasonic_EVQPUJ_EVQPUA
SW5: BOOT; Panasonic_EVQPUJ_EVQPUA
U1: ESP32-WROOM-32U
U2: PCM5102A; TSSOP-20_4.4x6.5mm_P0.65mm
U3: MCP73831-2-OT; SOT-23-5
U4: AP2112K-3.3; SOT-23-5
U5: LP2985-3.3; SOT-23-5

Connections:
+3V3: C1.1, C2.1, C4.1, C14.1, J3.2, J5.2, R1.1, R2.1, R9.1, U1.2 (VDD), U2.20 (DVDD), U4.3 (EN), U4.5 (VOUT)
+3V3A: C5.1, C6.1, C7.1, C16.1, U2.1 (CPVDD), U2.8 (AVDD), U5.3 (ON/~OFF), U5.5 (VOUT)
AUDIO_L: J2.T, U2.6 (OUTL)
AUDIO_R: J2.R, U2.7 (OUTR)
BTN_1: SW1.1, U1.8 (IO32)
BTN_2: SW2.1, U1.9 (IO33)
BTN_3: SW3.1, U1.12 (IO27)
CC1: J1.A5 (CC1), R3.1
CC2: J1.B5 (CC2), R4.1
CHG_LED_A: D1.2 (A), R6.2
CHG_PROG: R5.1, U3.5 (PROG)
CHG_STAT: D1.1 (K), U3.1 (STAT)
DAC_CAPM: C8.2, U2.4 (CAPM)
DAC_CAPP: C8.1, U2.2 (CAPP)
DAC_LDOO: C10.1, U2.18 (LDOO)
DAC_VNEG: C9.1, U2.5 (VNEG)
DAC_XSMT: R9.2, U2.17 (XSMT)
DTR: J5.5, Q1.2 (E), Q2.1 (B)
EN: C3.1, Q1.3 (C), R1.2, SW4.1, U1.3 (EN)
GND: C1.2, C2.2, C3.2, C4.2, C5.2, C6.2, C7.2, C9.2, C10.2, C11.2, C12.2, C13.2, C14.2, C15.2, C16.2, C17.2, C18.2, J1.A1 (GND), J1.A12 (GND), J1.B1 (GND), J1.B12 (GND), J1.SH (SHIELD), J2.S, J3.1, J4.2, J5.1, R3.2, R4.2, R5.2, R8.2, SW1.2, SW2.2, SW3.2, SW4.2, SW5.2, U1.1 (GND), U1.15 (GND), U1.38 (GND), U1.39 (GND), U2.3 (CPGND), U2.9 (AGND), U2.10 (DEMP), U2.11 (FLT), U2.12 (SCK), U2.16 (FMT), U2.19 (DGND), U3.2 (V_{SS}), U4.2 (GND), U5.2 (GND)
I2C_SCL: J3.3, U1.36 (IO22)
I2C_SDA: J3.4, U1.33 (IO21)
I2S_BCK: U1.26 (IO4), U2.13 (BCK)
I2S_DATA: JP1.2, U2.14 (DIN)
I2S_DATA_MCU: JP1.1, U1.24 (IO2)
I2S_LRCK: U1.23 (IO15), U2.15 (LRCK)
IO0: Q2.3 (C), R2.2, SW5.1, U1.25 (IO0)
RTS: J5.6, Q1.1 (B), Q2.2 (E)
RXD0: J5.3, U1.34 (RXD0/IO3)
TXD0: J5.4, U1.35 (TXD0/IO1)
U5_BYPASS: C17.1, U5.4 (BP)
VBAT: C12.1, C13.1, C15.1, J4.1, R7.1, U3.3 (V_{BAT}), U4.1 (VIN), U5.1 (VIN)
VBAT_SENSE: C18.1, R7.2, R8.1, U1.7 (IO35)
VBUS: C11.1, J1.A4 (VBUS), J1.A9 (VBUS), J1.B4 (VBUS), J1.B9 (VBUS), R6.1, U3.4 (V_{DD})

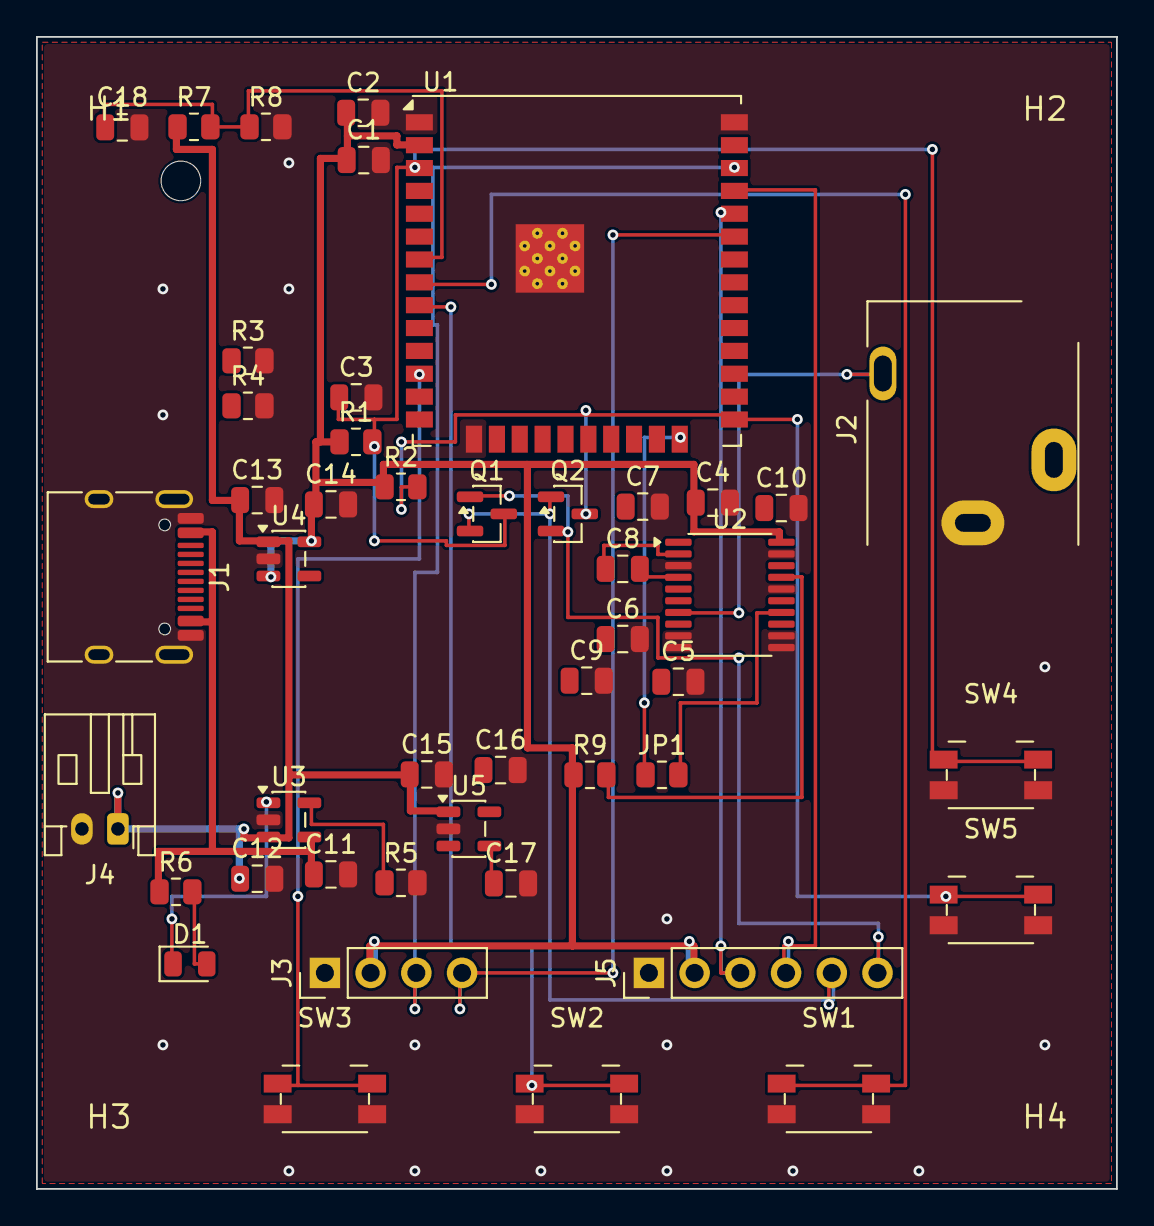
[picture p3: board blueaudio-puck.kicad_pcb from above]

Board: 2 copper layers, 60.0 x 64.0 mm, 50 parts (0 on the bottom side), 34 nets.

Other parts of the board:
H1, H2, H3, H4: (no value)

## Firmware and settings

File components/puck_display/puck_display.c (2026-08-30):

/*
 * SPDX-FileCopyrightText: 2026 Zektopic
 * SPDX-License-Identifier: MIT
 *
 * The status screen: what is playing, how loud, and how much battery is left.
 *
 * Two rates, deliberately. Track text and battery are read at 2 Hz -- reading
 * the track takes the AVRCP mutex, and a display has no business holding that
 * often. The marquee animates at 8 Hz from the cached copy, which is fast
 * enough to look smooth and costs nothing but a redraw.
 */

#include <stdio.h>
#include <string.h>

#include "esp_check.h"
#include "esp_log.h"
#include "freertos/FreeRTOS.h"
#include "freertos/task.h"

#include "bt_core.h"
#include "puck_avrcp.h"
#include "puck_battery.h"
#include "puck_display.h"
#include "ssd1306.h"

static const char *TAG = "puck_disp";

#define TASK_STACK        4096
#define TASK_PRIO         3
#define FRAME_MS          125   /* 8 Hz: marquee animation */
#define DATA_EVERY_FRAMES 4     /* 2 Hz: track and battery */

#define MARQUEE_PAUSE_FRAMES 8  /* hold at each end before sliding */
#define MARQUEE_STEP_PX      2

typedef struct {
    bool                  present;
    volatile puck_screen_t screen;
    TaskHandle_t          task;
    uint8_t               fb[SSD1306_FB_SIZE];

    /* Cached at the slow rate so the fast redraw touches no locks. */
    puck_track_info_t      track;
    puck_battery_reading_t battery;
    bt_core_link_quality_t link;
    uint8_t                volume;
    bool                   playing;

    int      marquee_px;
    int      marquee_hold;

    char     toast[22];
    uint32_t toast_frames;
} puck_display_t;

static puck_display_t s_disp;

static void refresh_data(void)
{
    puck_avrcp_get_track(&s_disp.track);
    puck_battery_get(&s_disp.battery);
    bt_core_link_quality_get(&s_disp.link);
    s_disp.volume = puck_avrcp_get_volume();
    s_disp.playing = puck_avrcp_is_playing();
}

/**
 * Top row: signal meter and link state on the left, power on the right.
 *
 * @param show_signal  Only when a source is connected. Bars against no link
 *                     would be meaningless, and an empty meter reads as a
 *                     fault rather than as "nothing to measure".
 */
static void draw_status_bar(const char *left, bool show_signal)
{
    int text_x = 0;

    if (show_signal) {
        gfx_signal_bars(s_disp.fb, 0, 0, s_disp.link.bars, s_disp.link.valid);
        text_x = SIGNAL_METER_WIDTH + 3;
    }
    gfx_text(s_disp.fb, text_x, 0, left, 1, true);

    if (s_disp.battery.state == PUCK_BATTERY_ABSENT) {
        /* No divider fitted, so there is nothing to report. Saying "USB" is
         * honest; showing a full battery icon would be a lie. */
        gfx_text(s_disp.fb, SSD1306_WIDTH - (3 * FONT_ADVANCE), 0, "USB", 1, true);
    } else if (!s_disp.battery.valid) {
        gfx_text(s_disp.fb, SSD1306_WIDTH - (3 * FONT_ADVANCE), 0, "...", 1, true);
    } else {
        char pct[6];
        snprintf(pct, sizeof(pct), "%u%%", s_disp.battery.percent);
        const int icon_x = SSD1306_WIDTH - 15;
        const int pct_x = icon_x - gfx_text_width(pct, 1) - 3;
        gfx_text(s_disp.fb, pct_x, 0, pct, 1, true);
        gfx_battery(s_disp.fb, icon_x, 0, s_disp.battery.percent);
    }

    gfx_hline(s_disp.fb, 0, 9, SSD1306_WIDTH, true);
}

/** Bottom row: transport state on the left, a volume bar on the right. */
static void draw_volume_row(void)
{
    const int y = SSD1306_HEIGHT - 9;

    gfx_text(s_disp.fb, 0, y, s_disp.playing ? "PLAY" : "PAUSE", 1, true);

    const int bar_x = 40;
    const int bar_w = SSD1306_WIDTH - bar_x - 26;
    gfx_rect(s_disp.fb, bar_x, y, bar_w, 7, true);

    const int fill = (s_disp.volume * (bar_w - 4)) / PUCK_VOLUME_MAX;
    if (fill > 0) {
        gfx_fill_rect(s_disp.fb, bar_x + 2, y + 2, fill, 3, true);
    }

    char pct[6];
    snprintf(pct, sizeof(pct), "%u%%", (unsigned)s_disp.volume * 100u / PUCK_VOLUME_MAX);
    gfx_text(s_disp.fb, SSD1306_WIDTH - gfx_text_width(pct, 1), y, pct, 1, true);
}

/**
 * Draw one line of text, scrolling it if it does not fit.
 *
 * Only the line that overflows scrolls, and it pauses at both ends -- text
 * that slides continuously is much harder to read than text that stops.
 */
static void draw_scrolling_line(int y, const char *text, int scale, bool animate)
{
    if (text == NULL || text[0] == '\0') {
        return;
    }

    const int width = gfx_text_width(text, scale);
    if (width <= SSD1306_WIDTH) {
        gfx_text(s_disp.fb, 0, y, text, scale, true);
        return;
    }

    gfx_text_window(s_disp.fb, 0, y, SSD1306_WIDTH, text, scale, s_disp.marquee_px);

    if (!animate) {
        return;
    }
    const int max_offset = width - SSD1306_WIDTH;
    if (s_disp.marquee_hold > 0) {
        s_disp.marquee_hold--;
    } else if (s_disp.marquee_px >= max_offset) {
        s_disp.marquee_px = 0;
        s_disp.marquee_hold = MARQUEE_PAUSE_FRAMES;
    } else {
        s_disp.marquee_px += MARQUEE_STEP_PX;
        if (s_disp.marquee_px >= max_offset) {
            s_disp.marquee_px = max_offset;
            s_disp.marquee_hold = MARQUEE_PAUSE_FRAMES;
        }
    }
}

static void draw_now_playing(void)
{
    draw_status_bar("BT", true);

    const char *title = s_disp.track.title[0] ? s_disp.track.title : "(no track info)";
    const char *artist = s_disp.track.artist[0] ? s_disp.track.artist : "";

    draw_scrolling_line(14, title, 2, true);
    if (artist[0] != '\0') {
        gfx_text(s_disp.fb, 0, 34, artist, 1, true);
    }

    draw_volume_row();
}

static void draw_centred(int y, const char *text, int scale)
{
    const int w = gfx_text_width(text, scale);
    gfx_text(s_disp.fb, (SSD1306_WIDTH - w) / 2, y, text, scale, true);
}

static void draw_frame(bool animate)
{
    gfx_clear(s_disp.fb);

    switch (s_disp.screen) {
    case PUCK_SCREEN_PAIRING:
        draw_status_bar("PAIRING", false);
        draw_centred(22, "Ready to", 1);
        draw_centred(34, "pair", 2);
        break;

    case PUCK_SCREEN_IDLE:
        draw_status_bar("IDLE", false);
        draw_centred(24, CONFIG_PUCK_BT_DEVICE_NAME, 1);
        draw_centred(40, "hold to pair", 1);
        break;

    case PUCK_SCREEN_NOW_PLAYING:
        draw_now_playing();
        break;

    case PUCK_SCREEN_SPLASH:
    default:
        draw_centred(16, "BlueAudio", 2);
        draw_centred(38, "Puck", 2);
        break;
    }

    /* A toast covers the bottom of whatever is underneath, so a volume change
     * is readable without losing the screen behind it. */
    if (s_disp.toast_frames > 0) {
        s_disp.toast_frames--;
        gfx_fill_rect(s_disp.fb, 0, SSD1306_HEIGHT - 14, SSD1306_WIDTH, 14, false);
        gfx_rect(s_disp.fb, 0, SSD1306_HEIGHT - 14, SSD1306_WIDTH, 14, true);
        draw_centred(SSD1306_HEIGHT - 10, s_disp.toast, 1);
    }

    (void)animate;
}
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

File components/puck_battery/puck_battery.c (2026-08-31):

/*
 * SPDX-FileCopyrightText: 2026 Zektopic
 * SPDX-License-Identifier: MIT
 *
 * Battery sensing: an ADC on a resistor divider, turned into a percentage.
 *
 * Be honest about what this can and cannot do. A percentage derived from
 * terminal voltage is an estimate, not a fuel gauge. Li-po voltage sags under
 * load -- at the ~150 mA this device draws while streaming, the same cell reads
 * materially lower than it does idle -- and the curve between 3.7 V and 3.9 V
 * is nearly flat, which is most of the useful capacity. A real gauge needs
 * coulomb counting (MAX17048 and friends).
 *
 * What this is good for: telling the difference between full, half, and about
 * to die. That is what a status screen needs.
 */

#include <string.h>

#include "esp_adc/adc_cali.h"
#include "esp_adc/adc_cali_scheme.h"
#include "esp_adc/adc_oneshot.h"
#include <inttypes.h>

#include "esp_check.h"
#include "esp_log.h"
#include "freertos/FreeRTOS.h"
#include "freertos/task.h"

#include "puck_battery.h"

static const char *TAG = "puck_batt";

#define SAMPLE_TASK_STACK   3072
#define SAMPLE_TASK_PRIO    3
#define OVERSAMPLE          16    /* raw reads averaged per sample */

/*
 * Li-po discharge curve, open circuit, 10% steps from empty to full.
 *
 * Deliberately a table rather than a formula: the real curve is flat in the
 * middle and steep at both ends, and any linear fit spends most of its life
 * wrong. Interpolating between these points is close enough for a status icon.
 */
static const uint16_t s_curve_mv[11] = {
    3300,  /*   0% -- treat as empty; below this a protection circuit cuts in */
    3600,  /*  10% */
    3700,  /*  20% */
    3730,  /*  30% */
    3770,  /*  40% */
    3790,  /*  50% */
    3820,  /*  60% */
    3870,  /*  70% */
    3920,  /*  80% */
    4000,  /*  90% */
    4200,  /* 100% -- a full cell off the charger */
};

typedef struct {
    adc_oneshot_unit_handle_t unit;
    adc_cali_handle_t         cali;      /*!< NULL if the chip has no eFuse calibration */
    adc_channel_t             channel;
    bool                      fitted;
    TaskHandle_t              task;
    puck_battery_cb_t         cb;
    bool                      warned_implausible;
    puck_battery_reading_t    reading;
    int32_t                   filtered_mv;  /*!< smoothed, -1 until the first sample */
} puck_battery_t;

static puck_battery_t s_bat;

/**
 * Map GPIO to an ADC1 channel.
 *
 * ADC1 only, on purpose: ADC2 is shared with the Wi-Fi radio and its readings
 * become unavailable whenever Wi-Fi is active. This firmware does not use
 * Wi-Fi today, but pinning to ADC1 removes the trap in advance.
 */
static int adc1_channel_for_gpio(int gpio)
{
    switch (gpio) {
    case 36: return ADC_CHANNEL_0;
    case 37: return ADC_CHANNEL_1;
    case 38: return ADC_CHANNEL_2;
    case 39: return ADC_CHANNEL_3;
    case 32: return ADC_CHANNEL_4;
    case 33: return ADC_CHANNEL_5;
    case 34: return ADC_CHANNEL_6;
    case 35: return ADC_CHANNEL_7;
    default: return -1;
    }
}

static uint8_t percent_from_mv(uint16_t mv)
{
    if (mv <= s_curve_mv[0]) {
        return 0;
    }
    if (mv >= s_curve_mv[10]) {
        return 100;
    }
    for (int i = 1; i <= 10; i++) {
        if (mv < s_curve_mv[i]) {
            const uint16_t lo = s_curve_mv[i - 1];
            const uint16_t hi = s_curve_mv[i];
            const uint32_t within = ((uint32_t)(mv - lo) * 10u) / (hi - lo);
            return (uint8_t)((i - 1) * 10u + within);
        }
    }
    return 100;
}

static puck_battery_state_t state_from_percent(uint8_t percent)
{
    if (percent <= CONFIG_PUCK_BATTERY_CRITICAL_PERCENT) {
        return PUCK_BATTERY_CRITICAL;
    }
    if (percent <= CONFIG_PUCK_BATTERY_LOW_PERCENT) {
        return PUCK_BATTERY_LOW;
    }
    return PUCK_BATTERY_OK;
}

/** One oversampled reading, in millivolts at the ADC pin. */
static bool read_pin_mv(int *out_mv)
{
    int32_t total = 0;
    int taken = 0;

    for (int i = 0; i < OVERSAMPLE; i++) {
        int raw = 0;
        if (adc_oneshot_read(s_bat.unit, s_bat.channel, &raw) != ESP_OK) {
            continue;
        }
        int mv = 0;
        if (s_bat.cali != NULL) {
            if (adc_cali_raw_to_voltage(s_bat.cali, raw, &mv) != ESP_OK) {
                continue;
            }
        } else {
            /* No eFuse calibration on this chip. 12-bit over the 11 dB
             * attenuation range is a rough nominal, and worth saying so
             * rather than pretending the number is trustworthy. */
            mv = (raw * 3100) / 4095;
        }
        total += mv;
        taken++;
    }

    if (taken == 0) {
        return false;
    }
    *out_mv = (int)(total / taken);
    return true;
}

static void sample_once(void)
{
    int pin_mv = 0;
    if (!read_pin_mv(&pin_mv)) {
        ESP_LOGW(TAG, "ADC read failed");
        return;
    }

    /* Undo the divider. Ratio is expressed in hundredths so a 2:1 divider is
     * 200 and odd resistor pairs stay expressible without floats. */
    const int32_t cell_mv = ((int32_t)pin_mv * CONFIG_PUCK_BATTERY_DIVIDER_RATIO_X100) / 100;

    /* A single-cell Li-po that is connected and not on fire sits between about
     * 3.0 V and 4.3 V. Outside that, the reading is not a battery: the usual
     * causes are a divider ratio that does not match the fitted resistors, or
     * PUCK_BATTERY_ADC_GPIO pointing at a pin with nothing on it. Say so once
     * rather than rendering a confident percentage from noise. */
    if (cell_mv < 2500 || cell_mv > 4600) {
        if (!s_bat.warned_implausible) {
            s_bat.warned_implausible = true;
            ESP_LOGW(TAG, "implausible cell voltage %" PRId32 " mV (pin %d mV, ratio %d.%02d)"
                          " -- check the divider resistors and PUCK_BATTERY_DIVIDER_RATIO_X100",
                     cell_mv, pin_mv,
                     CONFIG_PUCK_BATTERY_DIVIDER_RATIO_X100 / 100,
                     CONFIG_PUCK_BATTERY_DIVIDER_RATIO_X100 % 100);
        }
    }

    /* Exponential smoothing. Playback current draw makes the terminal voltage
     * jump around; without this the percentage flickers on screen. */
    if (s_bat.filtered_mv < 0) {
        s_bat.filtered_mv = cell_mv;
    } else {
        s_bat.filtered_mv += (cell_mv - s_bat.filtered_mv) / 4;
    }

    const puck_battery_state_t was = s_bat.reading.state;

    s_bat.reading.millivolts = (uint16_t)s_bat.filtered_mv;
    s_bat.reading.percent = percent_from_mv(s_bat.reading.millivolts);
    s_bat.reading.state = state_from_percent(s_bat.reading.percent);
    s_bat.reading.valid = true;

    if (s_bat.reading.state != was) {
        ESP_LOGI(TAG, "%u mV, %u%%, state %d", s_bat.reading.millivolts,
                 s_bat.reading.percent, s_bat.reading.state);
        if (s_bat.cb) {
            s_bat.cb(&s_bat.reading);
        }
    }
}
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

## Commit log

2026-08-30 chore: replace hello_world scaffold with project skeleton
    Turns the stock example into an actual project so later increments have
    somewhere to land:
    - `main/puck_main.c` replaces the hello_world demo with a boot banner that
    reports chip, flash and heap, and errors loudly if the part has no Bluetooth
    Classic (the S3/C3 cannot run A2DP at all).
    - `sdkconfig.defaults` pins the esp32 target and switches to the large
    single-app partition layout up front -- the Bluedroid Classic stack does not
    fit the 1 MB default.
    - README documents the signal chain, firmware task structure, planned PCM5102A
    wiring and the build commands.
    - GitHub Actions builds every PR against ESP-IDF v5.5.4 and repo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
2026-08-30 feat: A2DP sink with I2S output
    Makes the puck a working Bluetooth audio receiver. Two self-contained
    components rather than the IDF example's shared ones, which are pulled in by
    ${IDF_PATH} path and would make the repo unbuildable anywhere else.
    components/bt_core
    Stack bring-up (NVS, BR/EDR controller, Bluedroid) and a single-threaded
    work queue. Bluedroid callbacks run on its own task where blocking stalls
    the link, so event handling is dispatched onto an app task pinned to core 0
    beside the radio. BLE controller memory is released at init (~30 kB heap).
    Pairing advertises IO capability NONE, which is what the hardware actually
    has -- no display, no keypad, nothing to confirm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
    [audio_sink.c]
2026-08-30 feat: AVRCP remote control and volume
    Adds components/puck_avrcp in both AVRCP roles, and the gain stage the volume
    control needs.
    Target role: the phone owns the volume slider and pushes absolute volume down
    to us. Declaring ESP_AVRC_RN_VOLUME_CHANGE capability is what makes a source
    hand over absolute volume at all -- without it the phone's slider does
    nothing. Local changes answer the source's outstanding notification request so
    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
2026-08-30 feat: parametric equaliser in the render path
    Adds components/audio_dsp: a cascade of biquad sections per channel, run on
    the audio writer task between the ring buffer and the I2S write. Every
    reference project for this build ends up here; this is that piece, done
    without the pitfalls they each hit.
    Single-precision float rather than fixed point. The ESP32 has a hardware FPU
    and five bands of stereo at 44.1 kHz is a few hundred thousand multiply-adds
    per second, so fixed point would buy nothing and cost coefficient scaling
    headaches. Coefficients follow the Audio EQ Cookbook; sections use transposed
    direct form II.
    Design points that matter more than the filter maths:
    - Coefficients are r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
    [audio_sink.c]
2026-08-30 feat: button gestures and status LED
    Adds components/puck_ui: one multi-function button, two optional volume
    buttons, and a PWM status LED.
    The UI task is interrupt-driven, not polled. It sleeps on a task notification
    indefinitely and is woken by a GPIO edge, then polls at 20 ms only while a
    gesture or an LED animation is actually in flight. A task that ticks 50 times
    a second forever is precisely what would block deep sleep later, so this is
    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
2026-08-30 feat: radio, clock and idle power policy
    Adds components/puck_power. The honest framing, which the code comments
    repeat: the ESP32 running Bluetooth Classic is roughly three quarters of this
    device's current budget and nothing here changes that. What firmware can
    actually reach is the radio's transmit power and what the puck does with the
    hours it spends in a bag with nothing connected.
    - Transmit power capped, default 0 dBm rather than the top of the range. The
    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
2026-08-30 sec: close the metadata leak, the stack stall, and permanent pairability
    Acts on a security review of the firmware. Three findings were real and
    remotely reachable by nothing more exotic than a connected phone repeating an
    AVRCP metadata response.
    1. Unbounded heap leak (high)
    bt_core_dispatch had a deep-copy hook but no matching free hook. The only
    place the copied attr_text was released was the successful-handler path, so
    every disposal that skipped the handler -- a full queue, or shutdown --
    leaked it. A source emits one metadata event per attribute in a tight burst,
    so overrunning a 10-deep queue is easy and the leak is repeatable without
    limit. Added bt_core_free_t, i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
    [audio_sink.c, puck_ui.c]
2026-08-30 fix: bound the I2S write, close the writer wakeup gaps, publish EQ coefficients atomically
    Acts on a concurrency review. Two findings were HIGH and compose into
    permanent silence; the third is unreachable today but fires the moment the
    equaliser is switched on.
    1. i2s_channel_write(..., portMAX_DELAY) is not "wait forever" (high)
    That parameter is timeout_ms, and the driver feeds it to pdMS_TO_TICKS,
    which is 32-bit: portMAX_DELAY overflows to roughly twelve hours. On a
    disabled channel the write blocks on a semaphore only i2s_channel_enable()
    ever gives, so a writer that entered the call just after a stop wedged for
    half a day still holding a ring buffer item. The window is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
    [audio_sink.c]
2026-08-30 perf: skip flat bands entirely, hoist coefficients, cut prefetch latency
    Measured on the board: 5 stereo biquad sections cost 1337 us per 360-frame
    block, which is 8.163 ms of audio -- 16% of one core at 160 MHz, or about
    3.2% per band. That is the number the Hackaday DSP project left as an open
    question, and it says the ceiling is roughly 30 sections rather than the
    handful people assume.
    Changes, in order of what they buy:
    - Flat bands are left out of the published coefficient set entirely rather
    than flagged and skipped. A flat equaliser is the default and the common
    case; scanning five bypass flags per sample to discover there is nothing to
    do is pure waste. With every band flat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
2026-08-30 docs: full README and a docs/ handbook
    Rewrites the README as project documentation rather than a stub, and adds a
    docs/ folder for the material that does not belong on a landing page.
    README: what it does, the signal chain and firmware architecture as diagrams,
    the component map, wiring, build and flash commands, the gesture and LED
    reference, a full Kconfig table, and a "Measured" section separating what has
    actually been observed from what has not.
    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
2026-08-30 feat: battery sensing with an honest discharge curve
    Adds components/puck_battery: an ADC1 reading of a resistor divider, turned
    into a percentage and a coarse state (ok / low / critical).
    Unfitted by default. With PUCK_BATTERY_ADC_GPIO at -1 the component reports
    PUCK_BATTERY_ABSENT forever and never samples, so a USB-powered build needs no
    special case and the display can just say "USB". That matches the puck_ui
    convention where -1 means the part is not on the board.
    What it does not claim to be: a fuel gauge. A percentage from terminal voltage
    is an estimate. Li-po voltage sags under load -- at the ~150 mA this device
    draws while streaming, the same cell reads materially lower than it d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
    [puck_battery.c]
2026-08-30 feat: OLED status screen, and move I2S to the direct-solder pinout
    Adds components/puck_display: an SSD1306 128x64 panel over I2C showing what is
    playing, the transport state, volume and battery.
    The pin move comes first, because it is what made the display possible. I2S
    now runs on GPIO 4 (BCK), 15 (LRCK) and 2 (DATA), matching the layout that lets
    a PCM5102A board sit directly beneath the ESP32 on short solder bridges. I2C
    takes 21 and 22. The old map had I2S data on GPIO 22, which is the conventional
    I2C clock -- a straight collision with the OLED.
    Two consequences of that layout, both documented:
    - No MCLK wire. The PCM5102A derives its own clock once the SCK bridge on the
    board is s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
    [audio_sink.c, puck_display.c, puck_power.c]
2026-08-30 feat: link signal meter on the status bar
    Four ascending bars at the top left of the OLED, driven by the Bluetooth
    controller rather than by a sensor.
    The honest part, which shapes the whole feature: Bluetooth Classic has no
    absolute RSSI. esp_bt_gap_read_rssi_delta() returns a delta from the Golden
    Receive Power Range -- the window the controller works to keep the link inside
    -- and the header is explicit that zero means the RSSI is inside that range.
    So zero is healthy, and a well-behaved link reports zero most of the time. The
    meter sits full during normal use and only falls as the link degrades. That is
    correct, and it is the opposite of the intuition a phone's signal bars build,
    so th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
    [puck_display.c]
2026-08-30 hw: KiCad schematic and board for a single-board puck
    Adds hardware/: a KiCad 10 schematic and PCB for a carrier board carrying the
    ESP32-WROOM-32U, a PCM5102A, Li-po charging and two separate 3V3 rails, on
    60 x 55 mm.
    Both files are generated from one netlist in hardware/scripts/design.py. That
    is the point of the arrangement: a schematic and a board authored separately
    disagree about connectivity, and KiCad says nothing until someone runs ERC and
    gets a wall of errors. One source, two emitters, no drift. Symbols and
    footprints are copied out of the installed KiCad libraries rather than
    transcribed, so the outputs are self-contained and a hand-typed pin table --
    the same silent-failure cla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
    [blueaudio-puck.kicad_pcb, blueaudio-puck.kicad_sch, bom.csv]
2026-08-31 Enhance BlueAudio Puck design with auto-reset functionality and routing improvements
    - Updated `blueaudio-puck.kicad_pro` to include top-level schematic sheet.
    - Enhanced `design.py` with detailed documentation on auto-reset behavior and added components for manual reset.
    - Modified net connections to reflect changes in auto-reset circuitry.
    - Improved PCB generation script (`gen_pcb.py`) to handle new component placements and added ground pours for better GND connectivity.
    - Introduced a new routing script (`route.py`) for efficient signal routing, ensuring no nets are left half-connected.
    - Implemented a grid-based routing algorithm that prioritizes clear paths and avoids conflicts with ex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
    [blueaudio-puck.kicad_pcb]
2026-08-31 feat: three buttons instead of one with a timing test
    Replaces the single multi-function button with three, each doing one thing on
    a tap and one thing on a hold:
    BT1 (GPIO 32) tap: next track hold: volume up, repeating
    BT2 (GPIO 33) tap: play/pause hold: pairing (1.5s), forget bonds (5s)
    BT3 (GPIO 27) tap: previous track hold: volume down, repeating
    The old scheme piled next and previous onto double and triple taps. It worked
    and it was unpleasant: every skip was a timing test, the multi-click window
    added a third of a second of latency to the most common action, and a single
    bounced contact turned play/pause into a track change.
    puck_ui now reports (button, event) an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
    [puck_power.c, puck_ui.c]
2026-08-31 chore: ignore KiCad local state files
    blueaudio-puck.kicad_prl is per-user editor state -- open layers, zoom, last
    selected tool -- and rode along in the previous commit because the ignore rule
    for it lives on the unmerged hardware branch, while the file itself is
    untracked and survives a branch switch.
    Adding the rule here so it cannot happen again from main.
2026-08-31 fix: raise Bluetooth transmit power, and enable the battery sense pin
    Two field reports, two independent causes.
    Range was poor because the transmit power ceiling defaulted to level 4, which
    is 0 dBm, when the ESP32 will do level 7 at +9 dBm. That cap was mine, on the
    theory that the phone is usually in the same pocket so the top of the range
    spends current on range nobody uses. Optimistic: there is normally a body
    between the puck and the phone, and 9 dB is about eight times the power and
    nearly three times the free-space range. Most of the link budget was being
    thrown away to save a few milliamps.
    The ceiling now defaults to the maximum, and the floor power control may drop
    to is exposed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
    [puck_battery.c, puck_power.c]
2026-08-31 docs: describe the board as it actually is, not as it was
    hardware/README.md still said "the board is not routed. There are no tracks and
    no copper pours." That stopped being true once routing landed: there are now
    228 track segments, 72 vias and ground pours on both layers.
    It is still not finished, and the honest version is more useful than either the
    old claim or a vague one. DRC reports 23 electrical errors -- 18 clearance, 4
    hole clearance, 1 short -- and two nets, RTS and VBUS, that the router could
    not place at all. Those numbers are now in the file, broken down by kind, with
    the cosmetic silkscreen warnings separated from the ones that matter.
    Also records why the router stops at 2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
2026-08-31 hw: three user buttons, JLCPCB rules, and a router that models copper width
    Brings the board in line with the three-button firmware, and fixes three
    geometry bugs in the router that were producing copper which looked right and
    was not.
    Buttons. SW1/SW2/SW3 are now BT1/BT2/BT3 on GPIO 32/33/27, matching the
    firmware; RESET and BOOT move to SW4/SW5. They sit in a row along the bottom
    edge in the order a thumb expects -- previous, play, next. The board grew from
    60x55 to 60x64 to make room: the old bottom edge was already full of headers,
    and squeezing five switches into the sides would have put the two people press
    constantly behind the headphone jack.
    Worth recording: there is no LED on GPI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
    [blueaudio-puck.kicad_pcb, blueaudio-puck.kicad_sch, bom.csv]

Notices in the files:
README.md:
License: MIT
